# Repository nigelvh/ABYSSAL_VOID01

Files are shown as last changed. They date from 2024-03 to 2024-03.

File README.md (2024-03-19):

# ABYSSAL.NETWORK VOID01
A routing & switching learning platform built around the Raspberry Pi Compute Module 4, and the Microchip KSZ9477 gigabit ethernet switch.

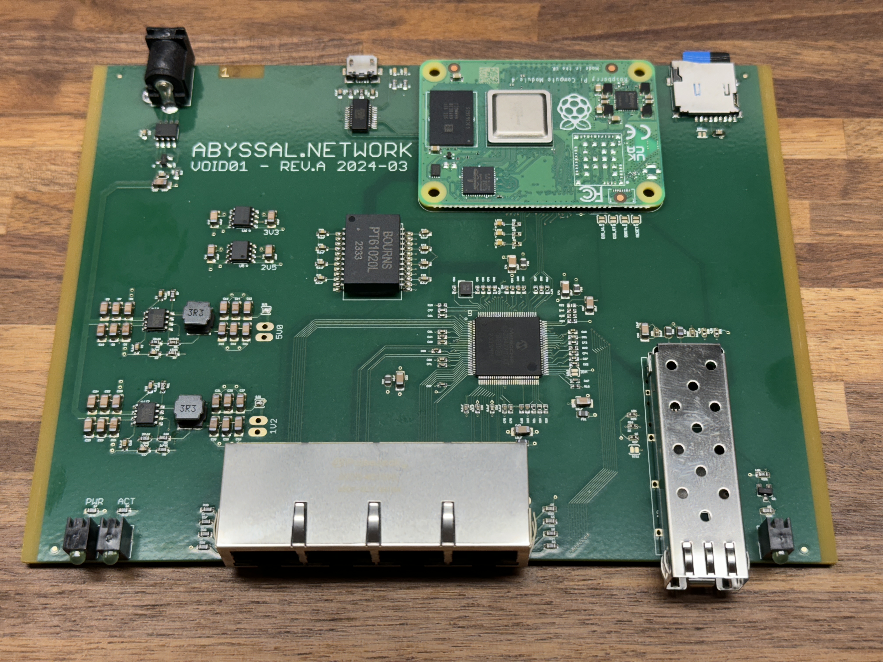
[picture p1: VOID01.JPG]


## Hardware
These are the hardware design files. They're almost certainly terrible. Replicate this device at your own peril.

## Software
The Raspberry Pi Compute Module is installed with standard Raspbian. Configuration of the switching functions of the KSZ9477 are done via scripts communicating via the SPI bus. Configuration of routing functions are as per standard Linux methods.

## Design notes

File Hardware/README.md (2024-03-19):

# ABYSSAL.NETWORK VOID01 Hardware
This is a custom routing and switching learning platform based on the Raspberry Pi Compute Module 4 and the Microchip KSZ9477 gigabit ethernet switch.

The RPi provides for a standard linux platform to enable easy development, with simple scripting to configure the KSZ9477, and linux routing functions. This provides a lower barrier to entry learning platform, as compared to an embedded processor of some sort.

A CM4 Lite module is chosen, utilizing SD card based storage to simplify installation of the RPi OS.

A USB serial interface is provided to allow access to the RPi Serial Console, allowing for non-network based access/recovery.

The KSZ9477 switch is an inexpensive off-the-shelf switching chip, with a relatively rich feature set. Providing 5 PHY interfaces (4 ethernet jacks, and 1 connected to the onboard RPi), 1 RGMII interface (not used), and 1 SGMII interface (SFP Port).

A standard center-positive barrel jack accepts nominal 12V DC power. The input range should be roughly 8-26V. Onboard regulation generates 5V, 3.3V, 2.5V, and 1.2V rails necessary for the RPi and KSZ9477.

## REV A 202403
The first revision of the board. Designed in March 2024.

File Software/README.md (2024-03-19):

# ABYSSAL.NETWORK VOID01 Software
This is a custom routing and switching learning platform based on the Raspberry Pi Compute Module 4 and the Microchip KSZ9477 gigabit ethernet switch.

The software functions remain a work in progress. Primarily based around simple python scripts allowing for control of the KSZ9477 configuration registers over the SPI bus.

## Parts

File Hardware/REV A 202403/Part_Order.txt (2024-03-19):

Index	DigiKey Part #	Manufacturer Part Number	Description	Customer Reference	Quantity	Backorder	Unit Price	Extended Price
1	YAG3023CT-ND	RC0402FR-07191RL	RES 191 OHM 1% 1/16W 0402		10	0	$0.01500	$0.15
2	311-1.00KLRCT-ND	RC0402FR-071KL	RES 1K OHM 1% 1/16W 0402		10	0	$0.01500	$0.15
3	311-4.7KLRCT-ND	RC0402FR-074K7L	RES 4.7K OHM 1% 1/16W 0402		10	0	$0.01500	$0.15
4	YAG2293CT-ND	RC0402FR-076K04L	RES 6.04K OHM 1% 1/16W 0402		10	0	$0.01500	$0.15
5	311-10.0KLRCT-ND	RC0402FR-0710KL	RES 10K OHM 1% 1/16W 0402		10	0	$0.01500	$0.15
6	311-10.0HRCT-ND	RC0603FR-0710RL	RES 10 OHM 1% 1/10W 0603		10	0	$0.02900	$0.29
7	311-22.0HRCT-ND	RC0603FR-0722RL	RES 22 OHM 1% 1/10W 0603		10	0	$0.01900	$0.19
8	311-27.0HRCT-ND	RC0603FR-0727RL	RES 27 OHM 1% 1/10W 0603		10	0	$0.01900	$0.19
9	311-1.00KHRCT-ND	RC0603FR-071KL	RES 1K OHM 1% 1/10W 0603		20	0	$0.01900	$0.38
10	311-3.74KHRCT-ND	RC0603FR-073K74L	RES 3.74K OHM 1% 1/10W 0603		10	0	$0.01900	$0.19
11	311-10.0KHRCT-ND	RC0603FR-0710KL	RES 10K OHM 1% 1/10W 0603		10	0	$0.01900	$0.19
12	311-11.0KHRCT-ND	RC0603FR-0711KL	RES 11K OHM 1% 1/10W 0603		10	0	$0.01900	$0.19
13	311-15.8KHRCT-ND	RC0603FR-0715K8L	RES 15.8K OHM 1% 1/10W 0603		10	0	$0.01900	$0.19
14	311-22.1KHRCT-ND	RC0603FR-0722K1L	RES 22.1K OHM 1% 1/10W 0603		10	0	$0.01900	$0.19
15	311-115KHRCT-ND	RC0603FR-07115KL	RES 115K OHM 1% 1/10W 0603		10	0	$0.01900	$0.19
16	1276-1075-1-ND	CL31A106KAHNNNE	CAP CER 10UF 25V X5R 1206		50	0	$0.07700	$3.85
17	1276-1043-1-ND	CL05A104KA5NNNC	CAP CER 0.1UF 25V X5R 0402		50	0	$0.00540	$0.27
18	1276-1179-1-ND	CL05C150JB5NNNC	CAP CER 15PF 50V C0G/NP0 0402		10	0	$0.02500	$0.25
19	1276-1935-1-ND	CL10B104KB8NNWC	CAP CER 0.1UF 50V X7R 0603		50	0	$0.01020	$0.51
20	311-1809-1-ND	CC0603KRX7R9BB272	CAP CER 2700PF 50V X7R 0603		10	0	$0.05800	$0.58
21	1934-1443-1-ND	2508051217Y3	FERRITE BEAD 120 OHM 0805 1LN		10	0	$0.07100	$0.71
22	2223-MSD-4-ACT-ND	MSD-4-A	MICRO SD CARD CONNECTOR, 9 POSIT		1	0	$0.35000	$0.35
23	CP-002AH-ND	PJ-002AH	CONN PWR JACK 2X5.5MM SOLDER		1	0	$0.69000	$0.69
24	A97430CT-ND	1367073-1	CONN SFP RCPT 20POS SLD R/A SMD		1	0	$1.93000	$1.93
25	A120616-ND	2227302-1	CONN SFP CAGE PRESS-FIT R/A		1	0	$2.23000	$2.23
26	PT61020ELCT-ND	PT61020EL	PULSE XFMR 1CT:1 350UH		1	0	$2.73000	$2.73
27	553-JXD0-4015NL-ND	JXD0-4015NL	CONN JACK 4PORT 1000 BASE-T PCB		1	0	$23.12000	$23.12
28	SRN6045TA-3R3YCT-ND	SRN6045TA-3R3Y	FIXED IND 3.3UH 5A 21 MOHM SMD		2	0	$0.54000	$1.08
29	1516-1224-ND	QBL7YG80D-MP4A	LED CBI 3MM GREEN DIFF RA		3	0	$0.55000	$1.65
30	3147-B1911UD--20D001014U1930CT-ND	B1911UD--20D001014U1930	LED ORANGE DIFFUSED 0603 SMD		10	0	$0.04700	$0.47
31	535-10297-1-ND	ABM8G-25.000MHZ-B4Y-T	CRYSTAL 25.0000MHZ 10PF SMD		1	0	$0.53000	$0.53
32	31-DMP31D1U-7CT-ND	DMP31D1U-7	MOSFET BVDSS: 25V~30V SOT23 T&R		1	0	$0.19000	$0.19
33	DMP4015SSS-13DICT-ND	DMP4015SSS-13	MOSFET P-CH 40V 9.1A 8SO		1	0	$0.81000	$0.81
34	31-AP64501SP-13CT-ND	AP64501SP-13	IC REG BUCK ADJUSTABLE 5A 8SO		2	0	$2.30000	$4.60
35	KSZ9477STXI-CT-ND	KSZ9477STXI-TR	IC ETHERNET SWITCH 7PORT 128TQFP		1	0	$20.91000	$20.91
36	31-AP7361EA-25SP-13CT-ND	AP7361EA-25SP-13	LDO CMOS HICURR SO-8EP T&R 2.5K		1	0	$0.44000	$0.44
37	31-AP7361EA-33SP-13CT-ND	AP7361EA-33SP-13	LDO CMOS HICURR SO-8EP T&R 2.5K		1	0	$0.44000	$0.44
38	MMBZ5242BLT3GOSCT-ND	MMBZ5242BLT3G	DIODE ZENER 12V 225MW SOT23-3		1	0	$0.14000	$0.14
39	2648-SC0683-ND	SC0683	SBC 1.5GHZ 4 CORE 4GB RAM		1	0	$50.00000	$50.00
42	609-4613-1-ND	10118192-0001LF	CONN RCPT USB2.0 MICRO B SMD R/A		1	0	$0.46000	$0.46
43	768-1129-1-ND	FT231XS-R	IC USB SERIAL FULL UART 20SSOP		1	0	$2.34000	$2.34
44	H11615CT-ND	DF40C-100DS-0.4V(51)	CONN RCPT 100POS SMD GOLD		1	0	$1.91000	$1.91

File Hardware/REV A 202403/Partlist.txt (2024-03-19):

Partlist

Exported from CM4_SWITCH.brd at 3/10/24 19:35

EAGLE Version 7.7.0 Copyright (c) 1988-2016 CadSoft

Assembly variant: 

Part     Value                      Package             Library  Position (inch)       Orientation
C85      15pF                       0402-CAP            SparkFun (3.55 2.35)           R90
C86      15pF                       0402-CAP            SparkFun (3.35 2.35)           R270
C37      0.1uF                      0402-CAP            SparkFun (4.35 1.7)            R0
C51      0.1uF                      0402-CAP            SparkFun (4.35 1.9)            R0
C52      0.1uF                      0402-CAP            SparkFun (3.7 2.35)            R90
C54      0.1uF                      0402-CAP            SparkFun (3.8 2.35)            R90
C55      0.1uF                      0402-CAP            SparkFun (3.6 2.35)            R90
C56      0.1uF                      0402-CAP            SparkFun (3.66 1.25)           R270
C57      0.1uF                      0402-CAP            SparkFun (3.25 1.46)           R180
C58      0.1uF                      0402-CAP            SparkFun (3.54 1.25)           R270
C59      0.1uF                      0402-CAP            SparkFun (3.2 1.77)            R180
C60      0.1uF                      0402-CAP            SparkFun (3.25 1.85)           R180
C61      0.1uF                      0402-CAP            SparkFun (3.25 2.1)            R180
C62      0.1uF                      0402-CAP            SparkFun (4.35 1.65)           R0
C64      0.1uF                      0402-CAP            SparkFun (3.25 1.9)            R180
C65      0.1uF                      0402-CAP            SparkFun (3.9 2.35)            R90
C66      0.1uF                      0402-CAP            SparkFun (3.95 2.35)           R90
C67      0.1uF                      0402-CAP            SparkFun (4.35 1.5)            R0
C68      0.1uF                      0402-CAP            SparkFun (4.35 1.95)           R0
C69      0.1uF                      0402-CAP            SparkFun (3.9 1.25)            R270
C70      0.1uF                      0402-CAP            SparkFun (3.81 1.25)           R270
C71      0.1uF                      0402-CAP            SparkFun (3.25 1.64)           R180
C72      0.1uF                      0402-CAP            SparkFun (4.35 1.85)           R0
C74      0.1uF                      0402-CAP            SparkFun (4.35 1.75)           R0
C75      0.1uF                      0402-CAP            SparkFun (3.76 1.25)           R270
C77      0.1uF                      0402-CAP            SparkFun (3.25 2.15)           R180
C78      0.1uF                      0402-CAP            SparkFun (3.45 1.25)           R270
C79      0.1uF                      0402-CAP            SparkFun (3.65 2.35)           R90
C80      0.1uF                      0402-CAP            SparkFun (3.25 1.69)           R180
C81      0.1uF                      0402-CAP            SparkFun (3.25 1.95)           R180
C82      0.1uF                      0402-CAP            SparkFun (4.1 2.35)            R90
C83      0.1uF                      0402-CAP            SparkFun (3.95 1.25)           R270
C84      0.1uF                      0402-CAP            SparkFun (3.85 2.35)           R90
C88      0.1uF                      0402-CAP            SparkFun (5.05 1.95)           R90
C90      0.1uF                      0402-CAP            SparkFun (5.35 1.95)           R90

C2       2.7nF                      0603-CAP            SparkFun (0.85 1.75)           R180
C17      2.7nF                      0603-CAP            SparkFun (0.85 0.9)            R180
C3       0.1uF                      0603-CAP            SparkFun (0.7 1.8)             R270
C4       0.1uF                      0603-CAP            SparkFun (0.85 2.3)            R90
C18      0.1uF                      0603-CAP            SparkFun (0.7 0.95)            R270
C19      0.1uF                      0603-CAP            SparkFun (0.85 1.45)           R90
C32      0.1uF                      0603-CAP            SparkFun (0.55 3.95)           R270
C34      0.1uF                      0603-CAP            SparkFun (0.75 3.5)            R0
C35      0.1uF                      0603-CAP            SparkFun (2.3 4.4)             R270
C36      0.1uF                      0603-CAP            SparkFun (2.6 4.4)             R90
C38      0.1uF                      0603-CAP            SparkFun (2.2 2.9)             R0
C39      0.1uF                      0603-CAP            SparkFun (2.2 2.75)            R0
C40      0.1uF                      0603-CAP            SparkFun (2.2 2.6)             R0
C41      0.1uF                      0603-CAP            SparkFun (2.2 2.45)            R0
C42      0.1uF                      0603-CAP            SparkFun (3.1 2.9)             R0
C43      0.1uF                      0603-CAP            SparkFun (3.1 2.75)            R0
C44      0.1uF                      0603-CAP            SparkFun (3.1 2.6)             R0
C45      0.1uF                      0603-CAP            SparkFun (3.1 2.45)            R0
C1       0.1uF                      0603-CAP            SparkFun (5.75 3.95)           R180

C5       10uF                       1206                SparkFun (0.6 2.15)            R90
C6       10uF                       1206                SparkFun (0.6 1.95)            R270
C7       10uF                       1206                SparkFun (0.5 2.15)            R90
C8       10uF                       1206                SparkFun (0.5 1.95)            R270
C9       10uF                       1206                SparkFun (0.4 2.15)            R90
C10      10uF                       1206                SparkFun (0.4 1.95)            R270
C11      10uF                       1206                SparkFun (1.6 1.95)            R270
C12      10uF                       1206                SparkFun (1.6 2.15)            R90
C13      10uF                       1206                SparkFun (1.5 1.95)            R270
C14      10uF                       1206                SparkFun (1.5 2.15)            R90
C15      10uF                       1206                SparkFun (1.4 1.95)            R270
C16      10uF                       1206                SparkFun (1.4 2.15)            R90
C20      10uF                       1206                SparkFun (0.6 1.3)             R90
C21      10uF                       1206                SparkFun (0.6 1.1)             R270
C22      10uF                       1206                SparkFun (0.5 1.3)             R90
C23      10uF                       1206                SparkFun (0.5 1.1)             R270
C24      10uF                       1206                SparkFun (0.4 1.3)             R90
C25      10uF                       1206                SparkFun (0.4 1.1)             R270
C26      10uF                       1206                SparkFun (1.6 1.1)             R270
C27      10uF                       1206                SparkFun (1.6 1.3)             R90
C28      10uF                       1206                SparkFun (1.5 1.1)             R270
C29      10uF                       1206                SparkFun (1.5 1.3)             R90
C30      10uF                       1206                SparkFun (1.4 1.1)             R270
C31      10uF                       1206                SparkFun (1.4 1.3)             R90
C33      10uF                       1206                SparkFun (0.75 3.4)            R0
C46      10uF                       1206                SparkFun (1.25 2.7)            R90
C47      10uF                       1206                SparkFun (1.25 3.05)           R90
C48      10uF                       1206                SparkFun (1.75 2.7)            R90
C49      10uF                       1206                SparkFun (1.75 3.05)           R90
C50      10uF                       1206                SparkFun (4.4 1.3)             R0
C53      10uF                       1206                SparkFun (2.9 1.5)             R270
C63      10uF                       1206                SparkFun (3.9 1.05)            R0
C73      10uF                       1206                SparkFun (4.3 2.35)            R90
C76      10uF                       1206                SparkFun (3.85 2.6)            R90
C87      10uF                       1206                SparkFun (4.5 2.2)             R90
C89      10uF                       1206                SparkFun (4.95 1.95)           R90

FB1                                 0805                SparkFun (4.4 1.2)             R180
FB2                                 0805                SparkFun (2.8 1.5)             R90
FB3                                 0805                SparkFun (3.9 0.95)            R180
FB4                                 0805                SparkFun (4.4 2.35)            R270
FB5                                 0805                SparkFun (3.95 2.6)            R270
FB6                                 0805                SparkFun (5.15 1.95)           R270
FB7                                 0805                SparkFun (5.25 1.95)           R270

FID1     FIDUCIAL                   FIDUCIAL            Nigel    (0.25 0.1)            R0
FID2     FIDUCIAL                   FIDUCIAL            Nigel    (6.05 0.1)            R0
FID3     FIDUCIAL                   FIDUCIAL            Nigel    (6.05 4.6)            R0
FID4     FIDUCIAL                   FIDUCIAL            Nigel    (0.25 4.6)            R0

J1       MICROSD                    MSD-4-A             Nigel    (5.65 4.55)           R180
J2       POWER_JACKPTH              POWER_JACK_PTH      SparkFun (0.75 4.8)            R180
J3       SFP+                       SFP_SOCKET_CAGE     Nigel    (4.95 1.4)            R90
J4       JXD0-4015NL                JXD0-4015NL         Nigel    (2.75 0.35)           R0

JP1                                 1X02_LONGPADS       SparkFun (1.75 2)              R270
JP2                                 1X02_LONGPADS       SparkFun (1.75 1.15)           R270

L1       3.3uH                      SRN6045TA           Nigel    (1.2 2.05)            R0
L2       3.3uH                      SRN6045TA           Nigel    (1.2 1.2)             R0

LED1     G                          LED-0603            SparkFun (3.75 2.8)            R270
LED2     Y                          LED-0603            SparkFun (3.75 2.9)            R270
LED3     G                          LED-0603            SparkFun (3.75 3)              R270
LED5     G                          LED-0603            SparkFun (2.8 4.65)            R0
LED7     G                          LED-0603            SparkFun (2.9 4.65)            R0
LED4     LED                        LED_QBL7XX80D-MP4A  Nigel    (0.5 0.2)             R0
LED6     LED                        LED_QBL7XX80D-MP4A  Nigel    (5.8 0.2)             R0
LED8     LED                        LED_QBL7XX80D-MP4A  Nigel    (0.75 0.2)            R0

Q1       MOSFET_P_CHANNELDMP4015SSS SO08                Nigel    (0.75 3.95)           R0
Q3       MOSFET_P_CHANNELAO3423     SOT-23              Nigel    (5.8 0.55)            R180

Q2                                  CRYSTAL_3.2X2.5     Nigel    (3.45 2.35)           R270

R22      191R                       0402-RES            SparkFun (4.35 1.8)            R0
R1       1K                         0402-RES            SparkFun (3.9 2.8)             R0
R2       1K                         0402-RES            SparkFun (3.9 2.9)             R0
R3       1K                         0402-RES            SparkFun (3.9 3)               R0
R26      1K                         0402-RES            SparkFun (4.8 1.1)             R0
R27      1K                         0402-RES            SparkFun (4.8 1)               R180
R16      4.7K                       0402-RES            SparkFun (4.15 2.35)           R90
R17      4.7K                       0402-RES            SparkFun (4.05 2.35)           R90
R30      4.7K                       0402-RES            SparkFun (5.45 1.95)           R270
R31      4.7K                       0402-RES            SparkFun (5.55 1.95)           R270
R15      6.04K                      0402-RES            SparkFun (3.25 2.2)            R180
R18      10K                        0402-RES            SparkFun (4.35 1.45)           R0
R19      10K                        0402-RES            SparkFun (4.1 1.25)            R270
R20      10K                        0402-RES            SparkFun (4.05 1.25)           R270
R21      10K                        0402-RES            SparkFun (4 1.25)              R270
R24      10K                        0402-RES            SparkFun (4.35 2.05)           R0
R25      10K                        0402-RES            SparkFun (4.35 2.1)            R0
R29      10K                        0402-RES            SparkFun (4.8 1.2)             R180
R44      10K                        0402-RES            SparkFun (4.35 2.15)           R0
R23      DNP                        0402-RES            SparkFun (4.35 2.2)            R0

R7       10R                        0603-RES            SparkFun (0.95 2.3)            R270
R11      22R                        0603-RES            SparkFun (0.95 1.45)           R270
R13      27                         0603-RES            SparkFun (2.5 4.4)             R270
R14      27                         0603-RES            SparkFun (2.4 4.4)             R270
R32      1K                         0603-RES            SparkFun (4.1 0.4)             R180
R33      1K                         0603-RES            SparkFun (4.1 0.3)             R180
R34      1K                         0603-RES            SparkFun (4.1 0.2)             R180
R35      1K                         0603-RES            SparkFun (4.1 0.1)             R180
R36      1K                         0603-RES            SparkFun (1.4 0.1)             R0
R37      1K                         0603-RES            SparkFun (1.4 0.3)             R0
R38      1K                         0603-RES            SparkFun (1.4 0.2)             R0
R39      1K                         0603-RES            SparkFun (1.4 0.4)             R0
R40      1K                         0603-RES            SparkFun (0.5 0.4)             R180
R41      1K                         0603-RES            SparkFun (2.8 4.5)             R90
R42      1K                         0603-RES            SparkFun (2.9 4.5)             R90
R43      1K                         0603-RES            SparkFun (0.75 0.4)            R180
R45      1K                         0603-RES            SparkFun (5.8 0.4)             R180
R8       3.74K                      0603-RES            SparkFun (1 0.9)               R180
R12      10K                        0603-RES            SparkFun (0.875 3.52)          R270
R28      10K                        0603-RES            SparkFun (5.8 0.7)             R180
R9       11K                        0603-RES            SparkFun (1 1)                 R180
R4       15.8K                      0603-RES            SparkFun (1 1.75)              R180
R6       22.1K                      0603-RES            SparkFun (0.85 1.85)           R180
R10      22.1K                      0603-RES            SparkFun (0.85 1)              R180
R5       115.8K                     0603-RES            SparkFun (1 1.85)              R180

SJ1                                 SJ_2S-TRACE         SparkFun (5.6 3.95)            R0
SJ2      NC                         SJ_2S-TRACE         SparkFun (4.5 3.45)            R270
SJ3      NO                         SJ_2S-NO            SparkFun (4.5 3.55)            R90
SJ4      NO                         SJ_2S-NO            SparkFun (4.65 3.05)           R90
SJ5      NO                         SJ_2S-NO            SparkFun (4.75 3.05)           R90
SJ6      NO                         SJ_2S-NO            SparkFun (4.85 3.05)           R90
SJ7      NO                         SJ_2S-NO            SparkFun (4.95 3.05)           R90
SJ8      NO                         SJ_2S-NO            SparkFun (1.75 1.3)            R0
SJ9      NO                         SJ_2S-NO            SparkFun (1.75 2.15)           R0
SJ10     NO                         SJ_2S-NO            SparkFun (4.35 1.58)           R90
SJ11     NO                         SJ_2S-NO            SparkFun (4.8 0.9)             R180

T1       HX6098NL                   HX6098NL            Nigel    (2.65 2.65)           R270
U$1      RPI-CM4                    RPI-CM4             Nigel    (5.2 4.7)             R180
         CM4 Hirose Connector		DF40C-100DS-0.4V(51)
U$2      USB-MICROB                 USB-MICROB-10118192 Nigel    (2.5 4.65)            R180
U1       AP64501                    SO-8EP              Nigel    (0.85 2.05)           R90
U2       AP64501                    SO-8EP              Nigel    (0.85 1.2)            R90
U3       KSZ9477S                   TQFP-128-EP         Nigel    (3.8 1.8)             R270
U4       FT231XS                    SSOP-20             Nigel    (2.5 4.1)             R90
U5       AP7361EA-25SP-13           SO-8EP              Nigel    (1.5 2.7)             R270
U6       AP7361EA-33SP-13           SO-8EP              Nigel    (1.5 3.05)            R270
Z1       12V                        SOT-23              Nigel    (0.75 3.65)           R90

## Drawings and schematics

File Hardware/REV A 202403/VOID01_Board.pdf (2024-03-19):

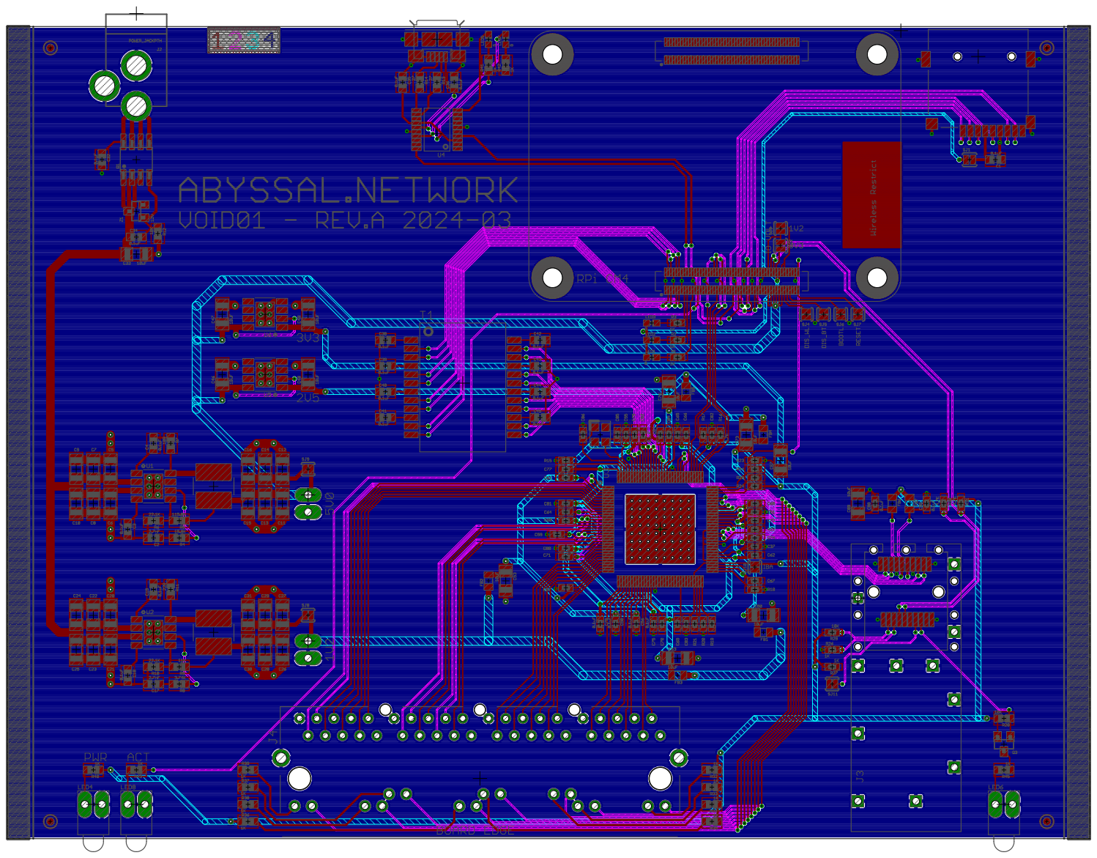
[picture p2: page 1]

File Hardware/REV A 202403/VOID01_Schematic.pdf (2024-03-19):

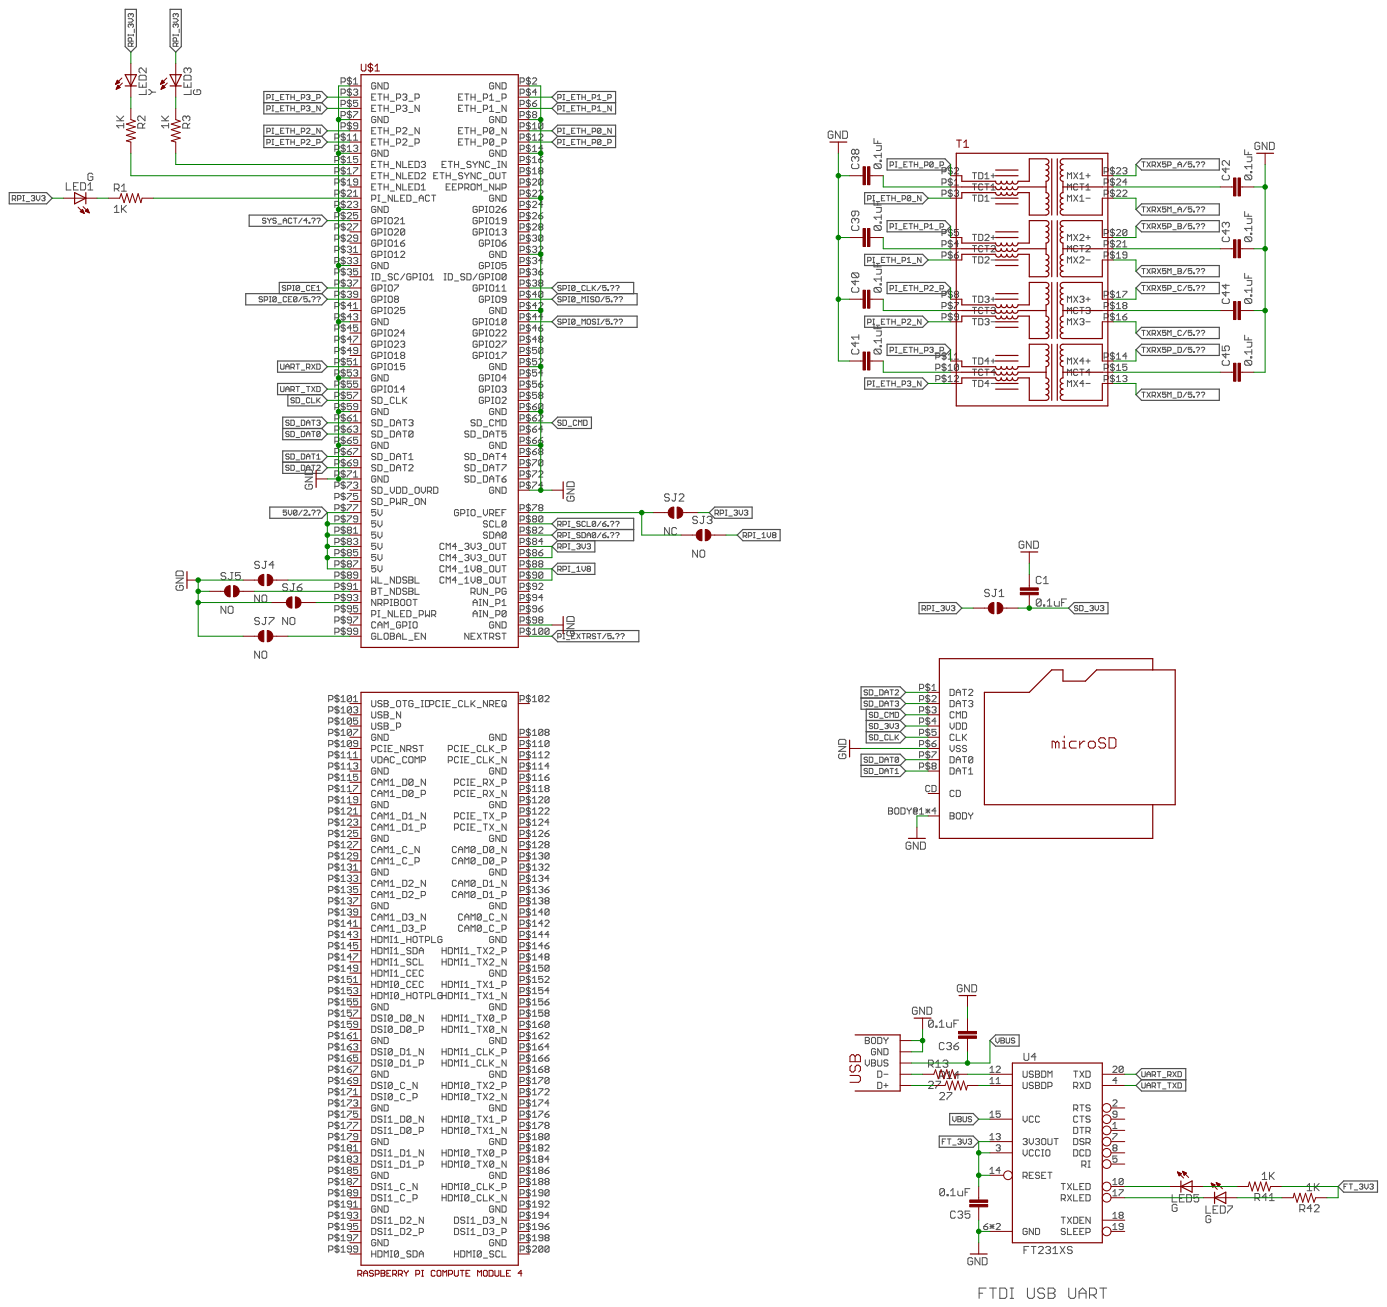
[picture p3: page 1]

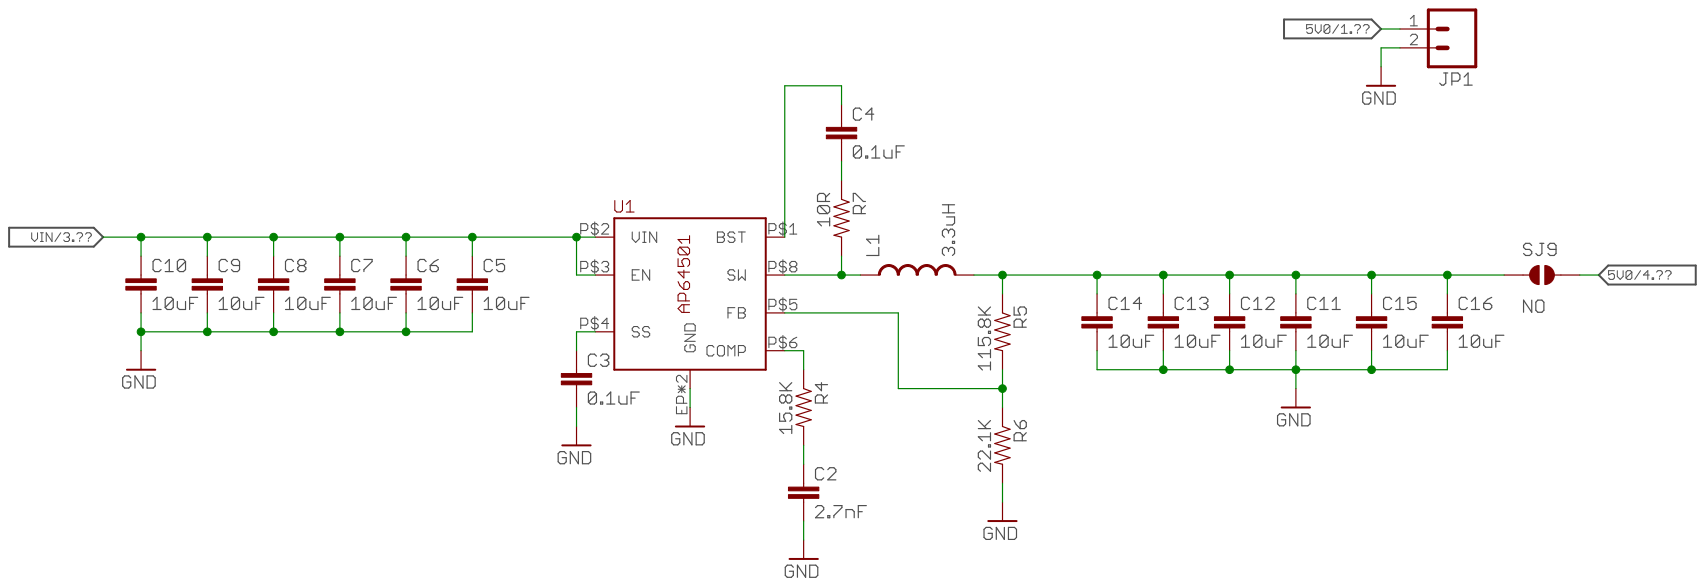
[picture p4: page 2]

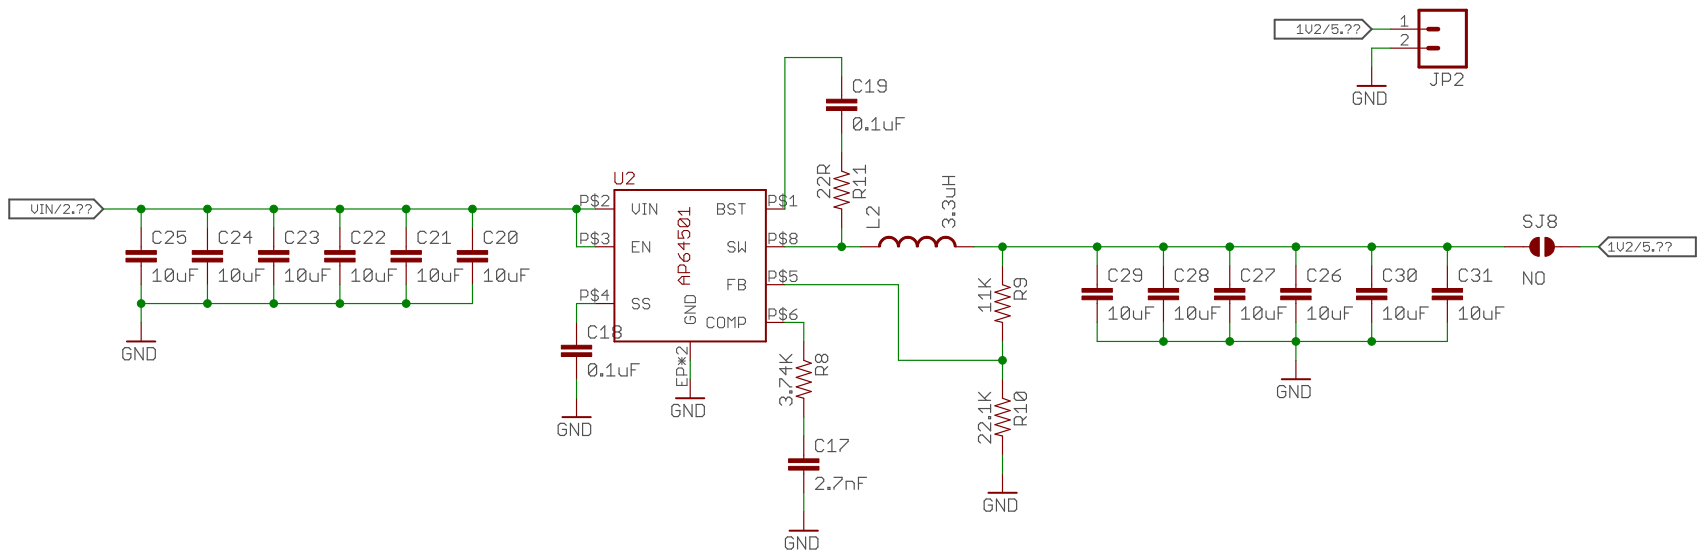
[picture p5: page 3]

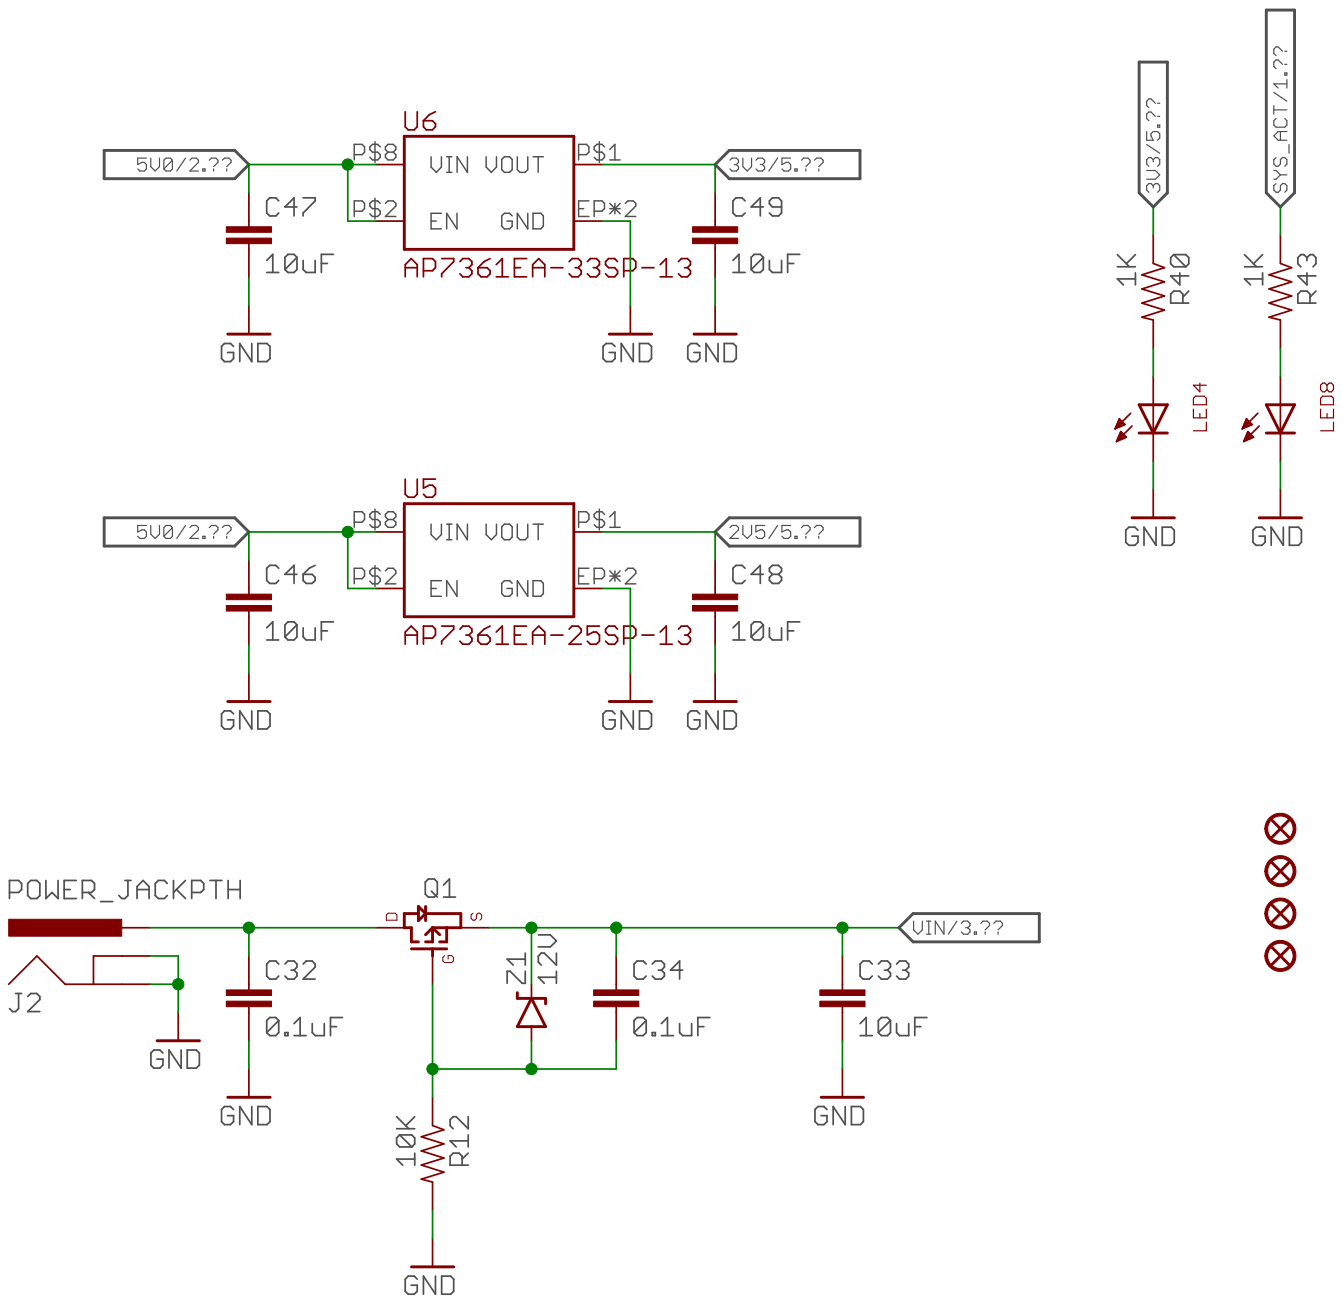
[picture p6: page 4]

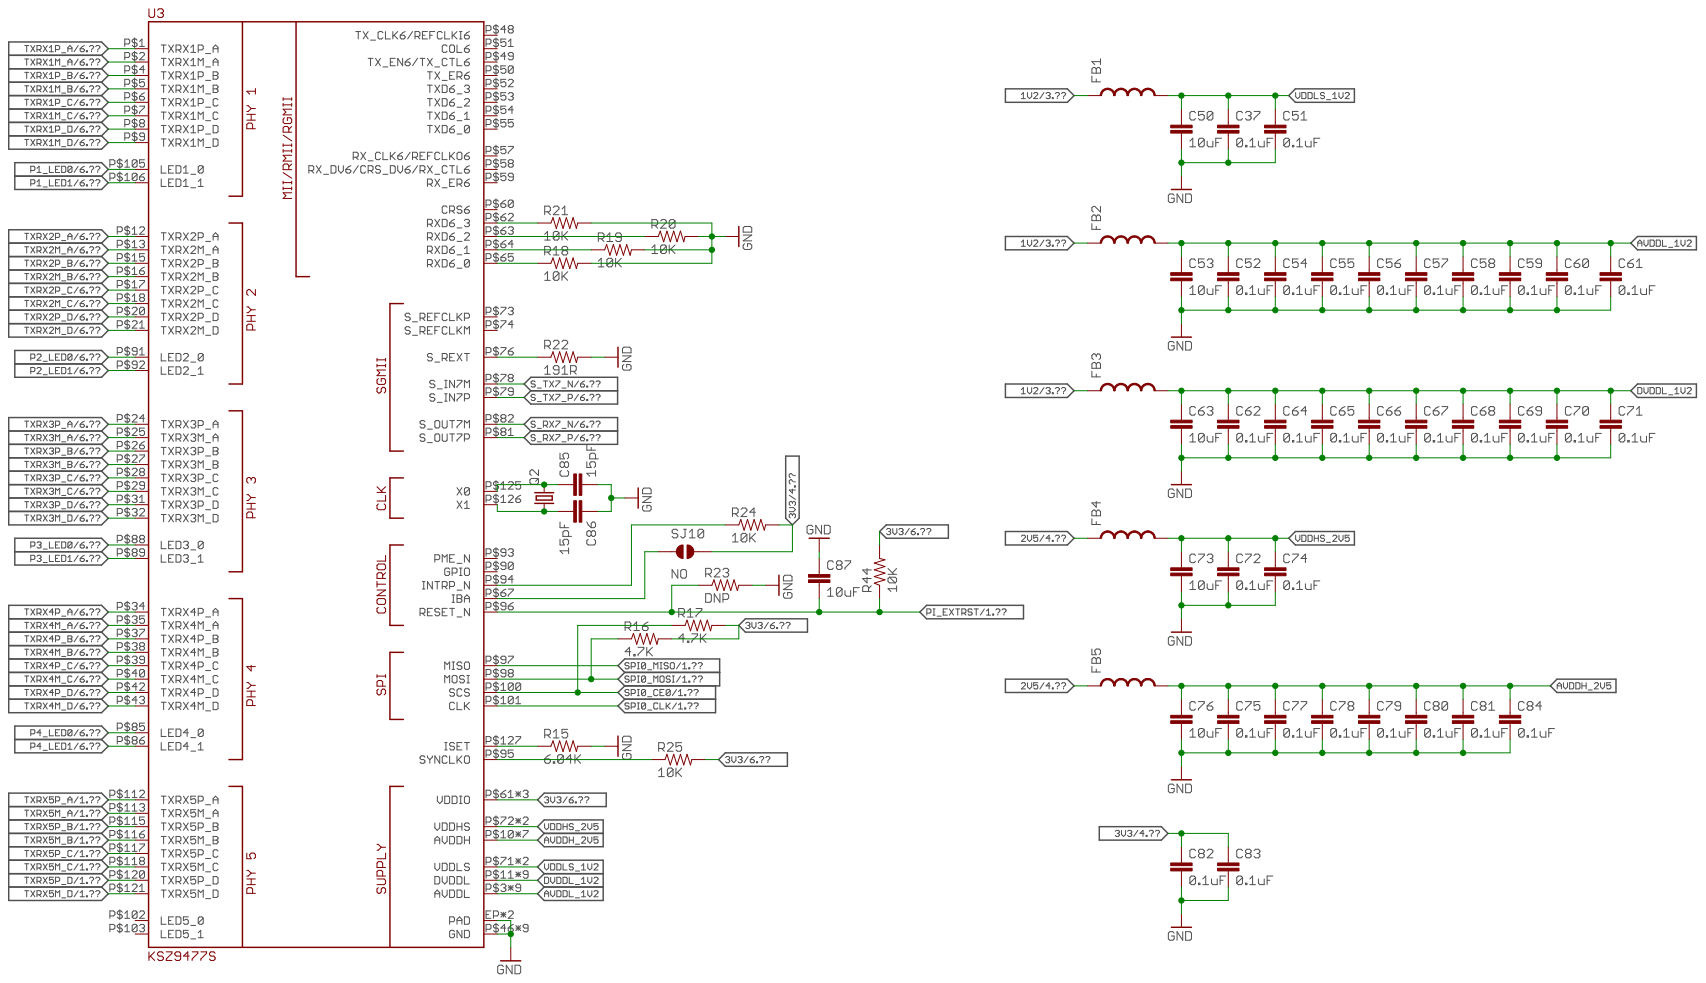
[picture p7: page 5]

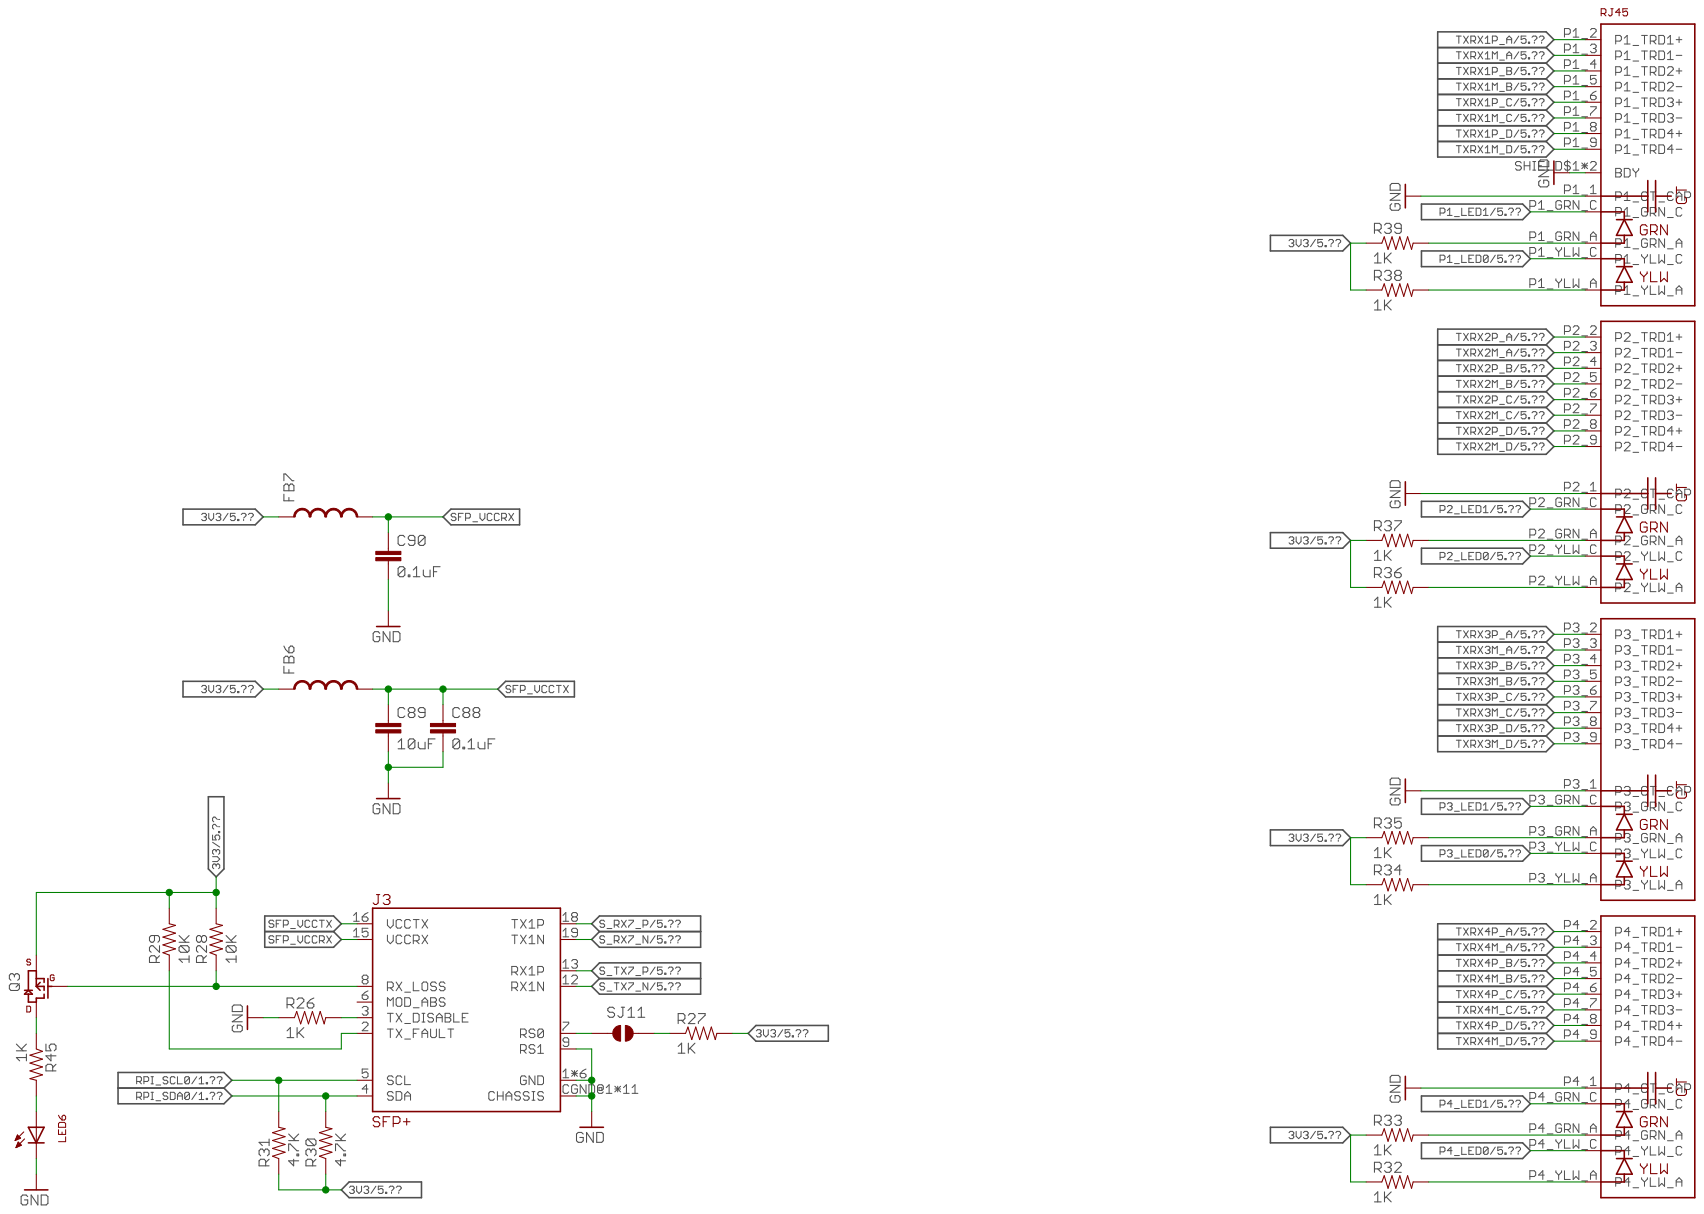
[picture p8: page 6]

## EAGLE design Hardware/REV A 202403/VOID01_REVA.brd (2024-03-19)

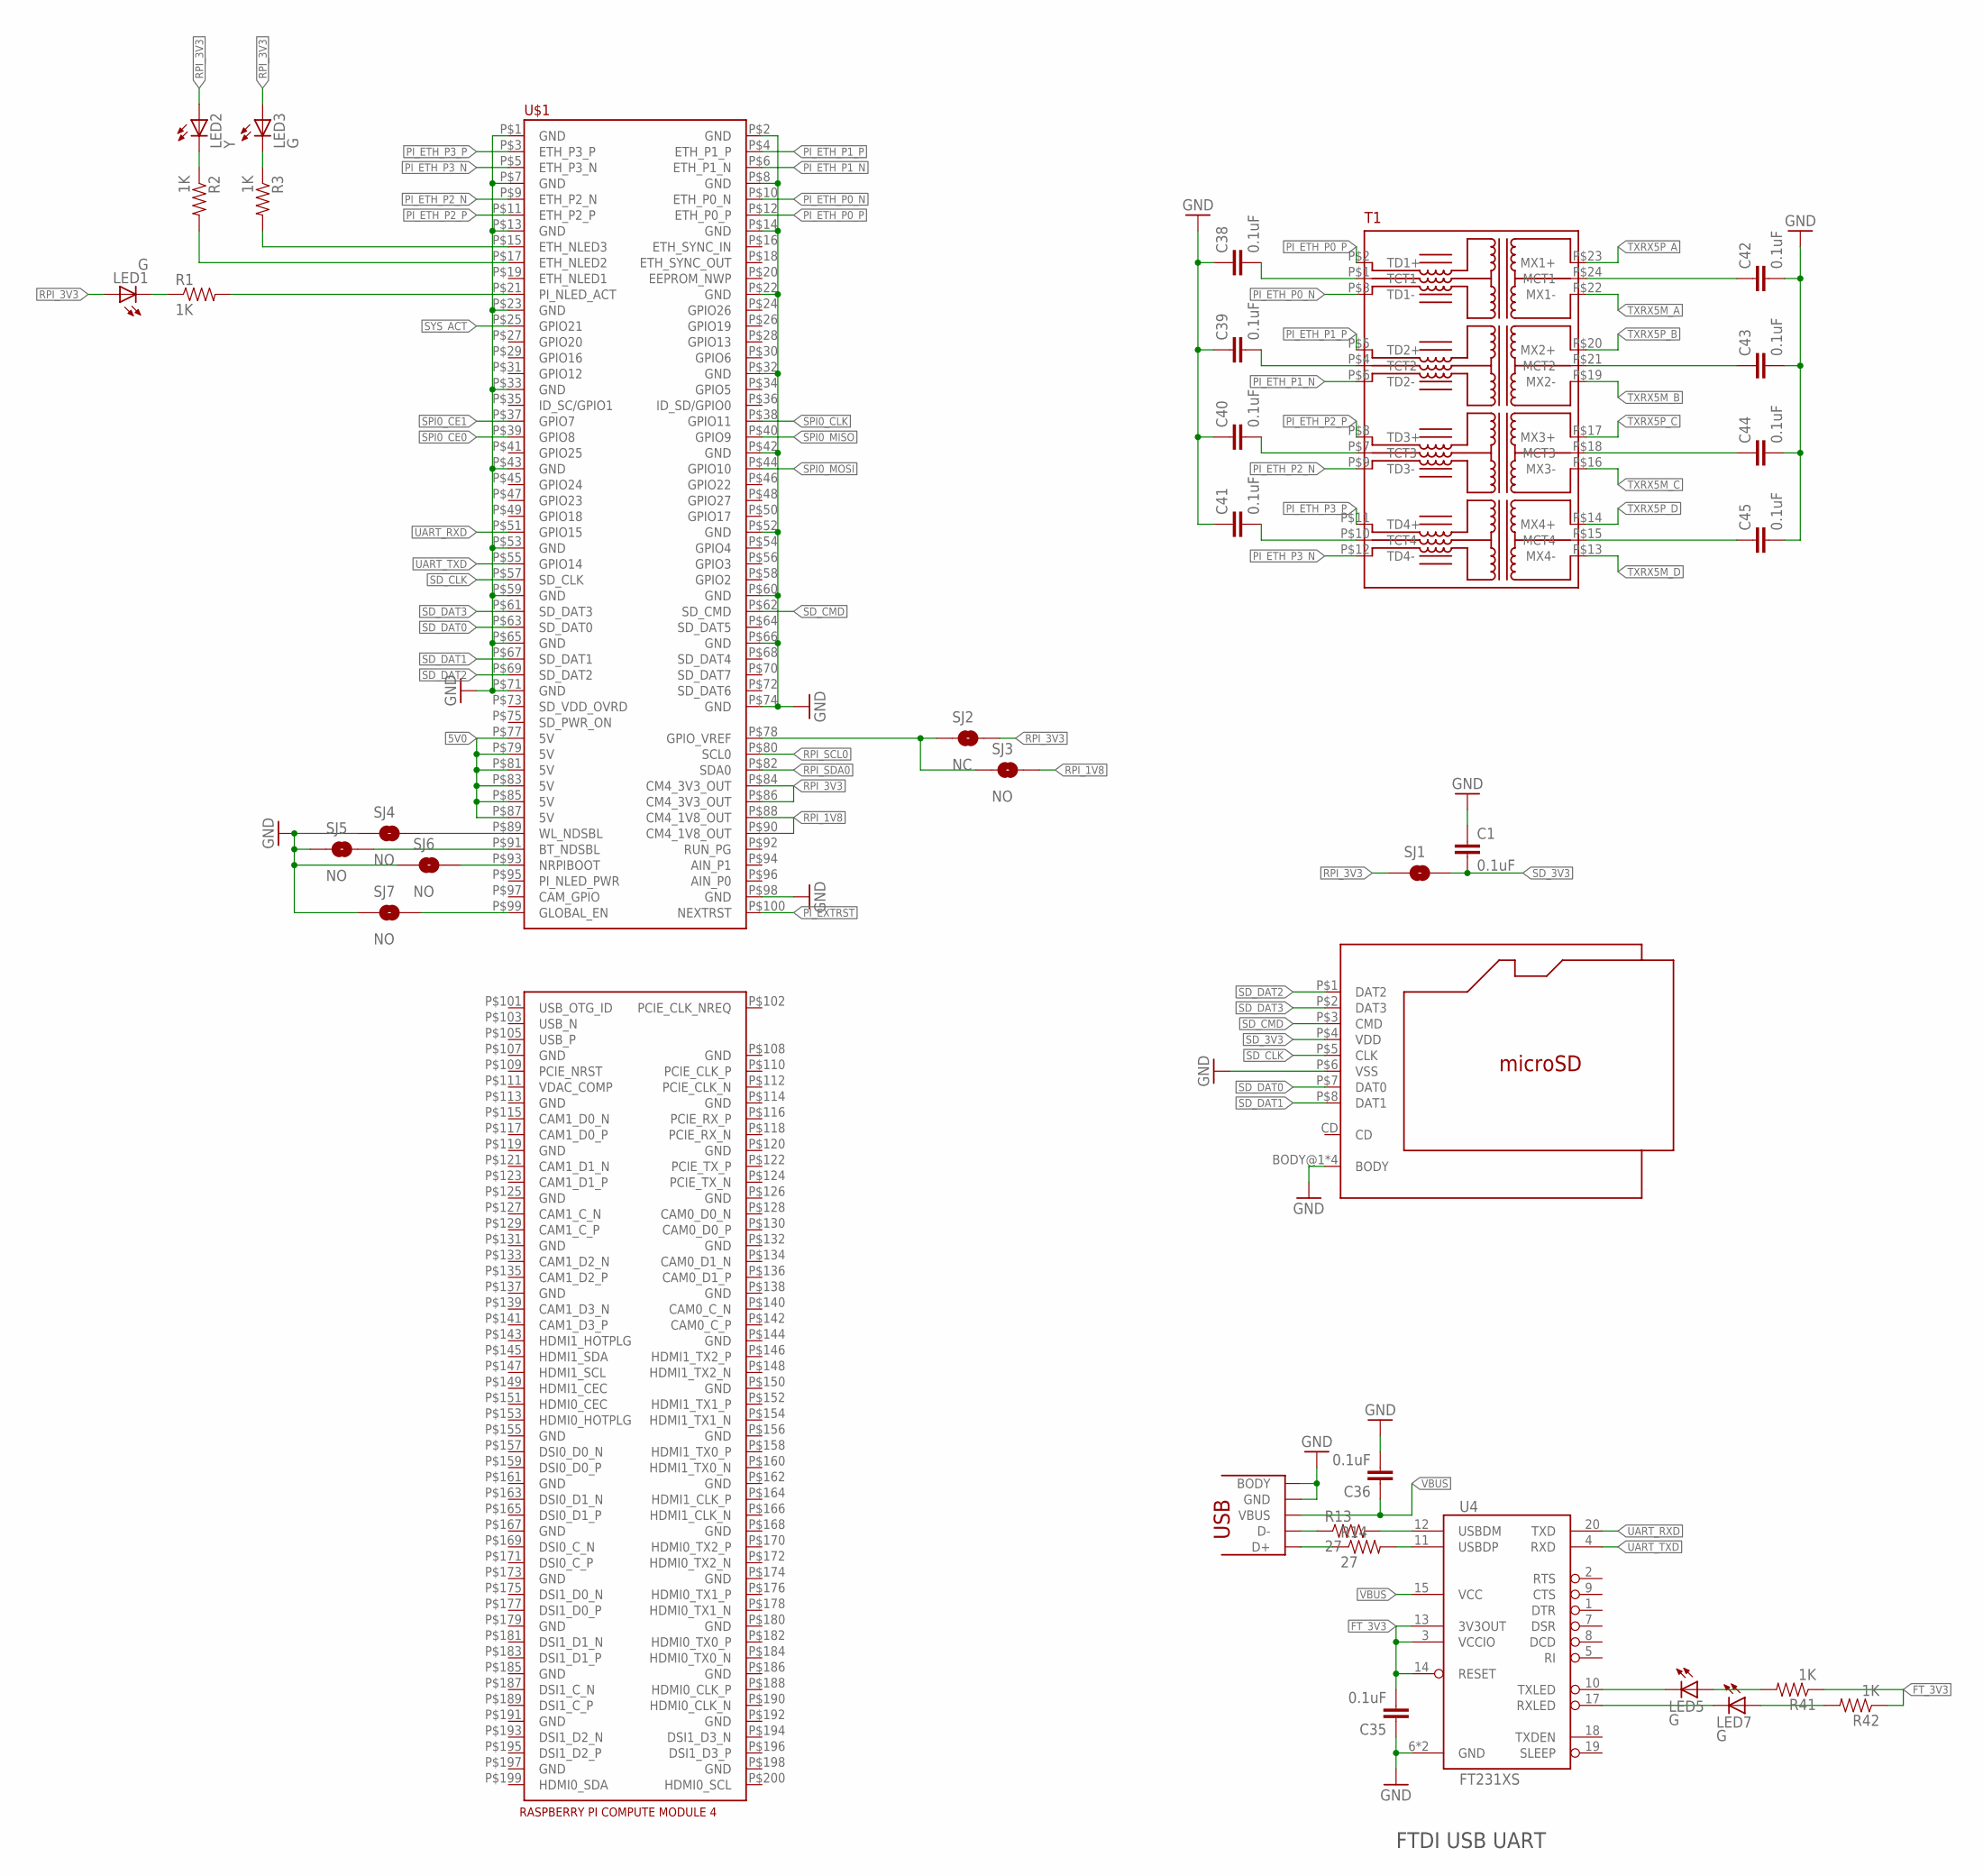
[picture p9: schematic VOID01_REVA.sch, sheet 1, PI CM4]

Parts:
C1, C35, C36, C38, C39, C40, C41, C42, C43, C44, C45: 0.1uF; 0603-CAP
J1: MICROSD; MSD-4-A
LED1, LED3, LED5, LED7: G; LED-0603
LED2: Y; LED-0603
R1, R2, R3: 1K; 0402-RES
R13, R14: 27; 0603-RES
R41, R42: 1K; 0603-RES
SJ1: SOLDERJUMPERTRACE; SJ_2S-TRACE
SJ2: NC; SJ_2S-TRACE
SJ3, SJ4, SJ5, SJ6, SJ7: NO; SJ_2S-NO
T1: HX6098NL
U4: FT231XS; SSOP-20
U$1: RPI-CM4
U$2: USB-MICROB; USB-MICROB-10118192

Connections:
5V0: U$1.P$77 (5V), U$1.P$79 (5V), U$1.P$81 (5V), U$1.P$83 (5V), U$1.P$85 (5V), U$1.P$87 (5V); also elsewhere on the board
FT_3V3: C35.2, R41.1, R42.1, U4.3 (VCCIO), U4.13 (3V3OUT), U4.14 (RESET)
GND: C1.1, C35.1, C36.2, C38.1, C39.1, C40.1, C41.1, C42.2, C43.2, C44.2, C45.2, J1.BODY@1 (BODY), J1.BODY@2 (BODY), J1.BODY@3 (BODY), J1.BODY@4 (BODY), J1.P$6 (VSS), SJ4.1, SJ5.1, SJ6.1, SJ7.1, U4.6 (GND), U4.16 (GND), U$1.P$1 (GND), U$1.P$2 (GND), U$1.P$7 (GND), U$1.P$8 (GND), U$1.P$13 (GND), U$1.P$14 (GND), U$1.P$22 (GND), U$1.P$23 (GND), U$1.P$32 (GND), U$1.P$33 (GND), U$1.P$42 (GND), U$1.P$43 (GND), U$1.P$52 (GND), U$1.P$53 (GND), U$1.P$59 (GND), U$1.P$60 (GND), U$1.P$65 (GND), U$1.P$66 (GND), U$1.P$71 (GND), U$1.P$74 (GND), U$1.P$98 (GND), U$2.5 (GND), U$2.BODY@1 (BODY), U$2.BODY@2 (BODY), U$2.BODY@3 (BODY), U$2.BODY@4 (BODY), U$2.BODY@5 (BODY), U$2.BODY@6 (BODY); also elsewhere on the board
unnamed: SJ2.1, SJ3.1, U$1.P$78 (GPIO_VREF)
unnamed: SJ4.2, U$1.P$89 (WL_NDSBL)
unnamed: SJ5.2, U$1.P$91 (BT_NDSBL)
unnamed: LED2.C, R2.1
unnamed: SJ6.2, U$1.P$93 (NRPIBOOT)
unnamed: R1.2, U$1.P$21 (PI_NLED_ACT)
unnamed: LED1.C, R1.1
unnamed: LED3.C, R3.1
unnamed: R2.2, U$1.P$17 (ETH_NLED2)
unnamed: R3.2, U$1.P$15 (ETH_NLED3)
unnamed: SJ7.2, U$1.P$99 (GLOBAL_EN)
unnamed: R13.1, U$2.2 (D-)
unnamed: R14.1, U$2.3 (D+)
unnamed: R14.2, U4.11 (USBDP)
unnamed: R13.2, U4.12 (USBDM)
unnamed: C38.2, T1.P$1 (TCT1)
unnamed: C39.2, T1.P$4 (TCT2)
unnamed: C40.2, T1.P$7 (TCT3)
unnamed: C41.2, T1.P$10 (TCT4)
unnamed: C45.1, T1.P$15 (MCT4)
unnamed: C44.1, T1.P$18 (MCT3)
unnamed: C43.1, T1.P$21 (MCT2)
unnamed: C42.1, T1.P$24 (MCT1)
unnamed: LED5.C, U4.10 (TXLED)
unnamed: LED5.A, R41.2
unnamed: LED7.C, U4.17 (RXLED)
unnamed: LED7.A, R42.2
PI_ETH_P0_N: T1.P$3 (TD1-), U$1.P$10 (ETH_P0_N)
PI_ETH_P0_P: T1.P$2 (TD1+), U$1.P$12 (ETH_P0_P)
PI_ETH_P1_N: T1.P$6 (TD2-), U$1.P$6 (ETH_P1_N)
PI_ETH_P1_P: T1.P$5 (TD2+), U$1.P$4 (ETH_P1_P)
PI_ETH_P2_N: T1.P$9 (TD3-), U$1.P$9 (ETH_P2_N)
PI_ETH_P2_P: T1.P$8 (TD3+), U$1.P$11 (ETH_P2_P)
PI_ETH_P3_N: T1.P$12 (TD4-), U$1.P$5 (ETH_P3_N)
PI_ETH_P3_P: T1.P$11 (TD4+), U$1.P$3 (ETH_P3_P)
PI_EXTRST: U$1.P$100 (NEXTRST); also elsewhere on the board
RPI_1V8: SJ3.2, U$1.P$88 (CM4_1V8_OUT), U$1.P$90 (CM4_1V8_OUT)
RPI_3V3: LED1.A, LED2.A, LED3.A, SJ1.1, SJ2.2, U$1.P$84 (CM4_3V3_OUT), U$1.P$86 (CM4_3V3_OUT)
RPI_SCL0: U$1.P$80 (SCL0); also elsewhere on the board
RPI_SDA0: U$1.P$82 (SDA0); also elsewhere on the board
SD_3V3: C1.2, J1.P$4 (VDD), SJ1.2
SD_CLK: J1.P$5 (CLK), U$1.P$57 (SD_CLK)
SD_CMD: J1.P$3 (CMD), U$1.P$62 (SD_CMD)
SD_DAT0: J1.P$7 (DAT0), U$1.P$63 (SD_DAT0)
SD_DAT1: J1.P$8 (DAT1), U$1.P$67 (SD_DAT1)
SD_DAT2: J1.P$1 (DAT2), U$1.P$69 (SD_DAT2)
SD_DAT3: J1.P$2 (DAT3), U$1.P$61 (SD_DAT3)
SPI0_CE0: U$1.P$39 (GPIO8); also elsewhere on the board
SPI0_CE1: U$1.P$37 (GPIO7)
SPI0_CLK: U$1.P$38 (GPIO11); also elsewhere on the board
SPI0_MISO: U$1.P$40 (GPIO9); also elsewhere on the board
SPI0_MOSI: U$1.P$44 (GPIO10); also elsewhere on the board
SYS_ACT: U$1.P$25 (GPIO21); also elsewhere on the board
TXRX5M_A: T1.P$22 (MX1-); also elsewhere on the board
TXRX5M_B: T1.P$19 (MX2-); also elsewhere on the board
TXRX5M_C: T1.P$16 (MX3-); also elsewhere on the board
TXRX5M_D: T1.P$13 (MX4-); also elsewhere on the board
TXRX5P_A: T1.P$23 (MX1+); also elsewhere on the board
TXRX5P_B: T1.P$20 (MX2+); also elsewhere on the board
TXRX5P_C: T1.P$17 (MX3+); also elsewhere on the board
TXRX5P_D: T1.P$14 (MX4+); also elsewhere on the board
UART_RXD: U4.20 (TXD), U$1.P$51 (GPIO15)
UART_TXD: U4.4 (RXD), U$1.P$55 (GPIO14)
VBUS: C36.1, U4.15 (VCC), U$2.1 (VBUS)

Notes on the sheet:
FTDI USB UART

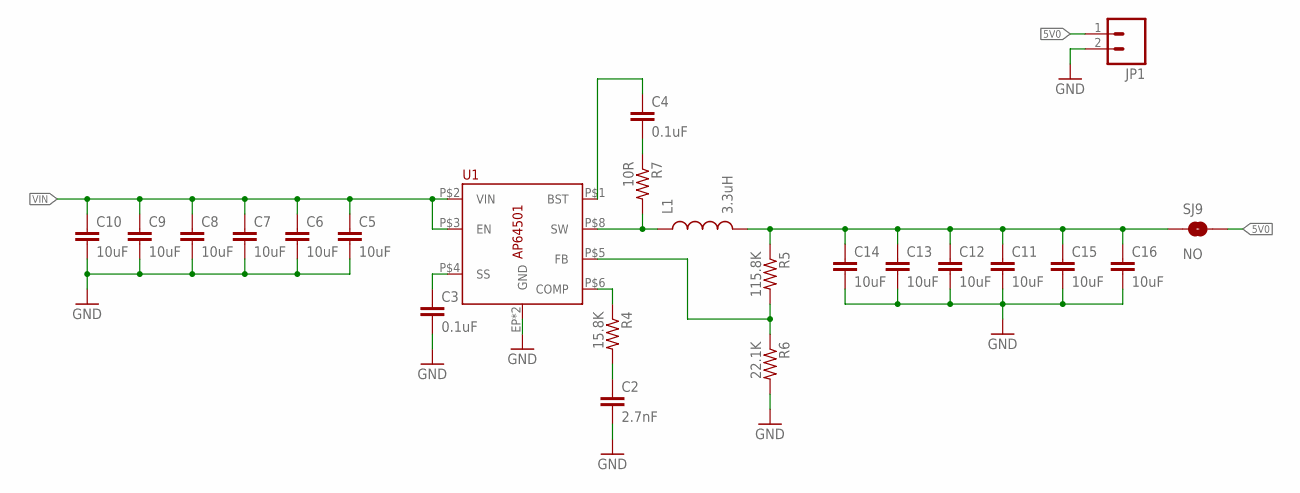
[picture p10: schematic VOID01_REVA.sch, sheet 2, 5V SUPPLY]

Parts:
C2: 2.7nF; 0603-CAP
C3, C4: 0.1uF; 0603-CAP
C5, C6, C7, C8, C9, C10, C11, C12, C13, C14, C15, C16: 10uF; 1206
JP1: M02PTH3; 1X02_LONGPADS
L1: 3.3uH; SRN6045TA
R4: 15.8K; 0603-RES
R5: 115.8K; 0603-RES
R6: 22.1K; 0603-RES
R7: 10R; 0603-RES
SJ9: NO; SJ_2S-NO
U1: AP64501; SO-8EP

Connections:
5V0: JP1.1, SJ9.2; also elsewhere on the board
GND: C2.2, C3.2, C5.2, C6.2, C7.2, C8.2, C9.2, C10.2, C11.2, C12.2, C13.2, C14.2, C15.2, C16.2, JP1.2, R6.2, U1.EP (GND), U1.P$7 (GND); also elsewhere on the board
unnamed: C3.1, U1.P$4 (SS)
unnamed: R4.1, U1.P$6 (COMP)
unnamed: C2.1, R4.2
unnamed: R5.2, R6.1, U1.P$5 (FB)
unnamed: L1.P$1 (1), R7.2, U1.P$8 (SW)
unnamed: C4.2, R7.1
unnamed: C4.1, U1.P$1 (BST)
unnamed: C11.1, C12.1, C13.1, C14.1, C15.1, C16.1, L1.P$2 (2), R5.1, SJ9.1
VIN: C5.1, C6.1, C7.1, C8.1, C9.1, C10.1, U1.P$2 (VIN), U1.P$3 (EN); also elsewhere on the board

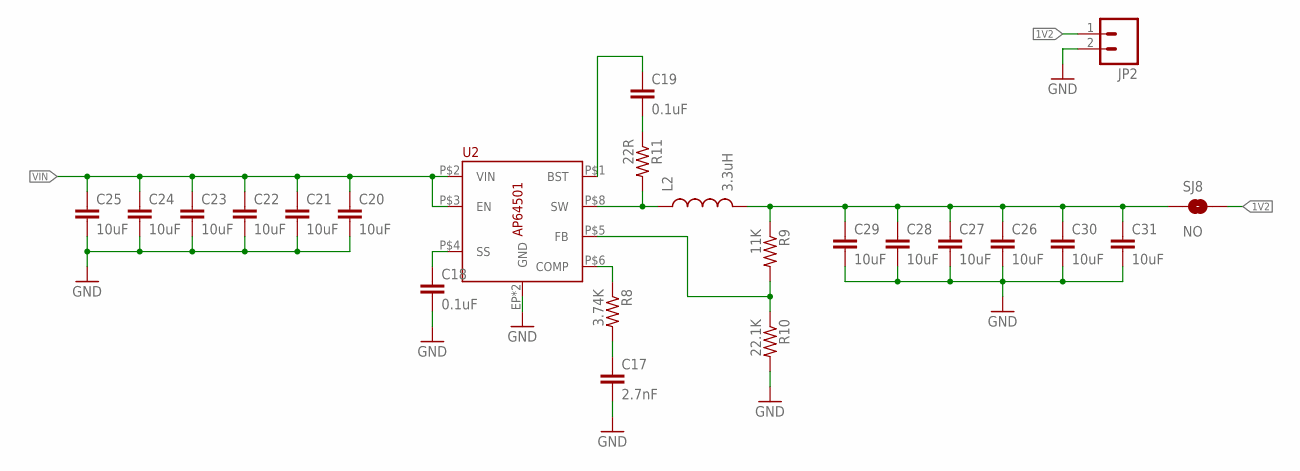
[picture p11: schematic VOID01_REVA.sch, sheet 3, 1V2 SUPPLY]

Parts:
C17: 2.7nF; 0603-CAP
C18, C19: 0.1uF; 0603-CAP
C20, C21, C22, C23, C24, C25, C26, C27, C28, C29, C30, C31: 10uF; 1206
JP2: M02PTH3; 1X02_LONGPADS
L2: 3.3uH; SRN6045TA
R8: 3.74K; 0603-RES
R9: 11K; 0603-RES
R10: 22.1K; 0603-RES
R11: 22R; 0603-RES
SJ8: NO; SJ_2S-NO
U2: AP64501; SO-8EP

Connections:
1V2: JP2.1, SJ8.2; also elsewhere on the board
GND: C17.2, C18.2, C20.2, C21.2, C22.2, C23.2, C24.2, C25.2, C26.2, C27.2, C28.2, C29.2, C30.2, C31.2, JP2.2, R10.2, U2.EP (GND), U2.P$7 (GND); also elsewhere on the board
unnamed: C18.1, U2.P$4 (SS)
unnamed: R8.1, U2.P$6 (COMP)
unnamed: C17.1, R8.2
unnamed: R9.2, R10.1, U2.P$5 (FB)
unnamed: L2.P$1 (1), R11.2, U2.P$8 (SW)
unnamed: C19.2, R11.1
unnamed: C19.1, U2.P$1 (BST)
unnamed: C26.1, C27.1, C28.1, C29.1, C30.1, C31.1, L2.P$2 (2), R9.1, SJ8.1
VIN: C20.1, C21.1, C22.1, C23.1, C24.1, C25.1, U2.P$2 (VIN), U2.P$3 (EN); also elsewhere on the board

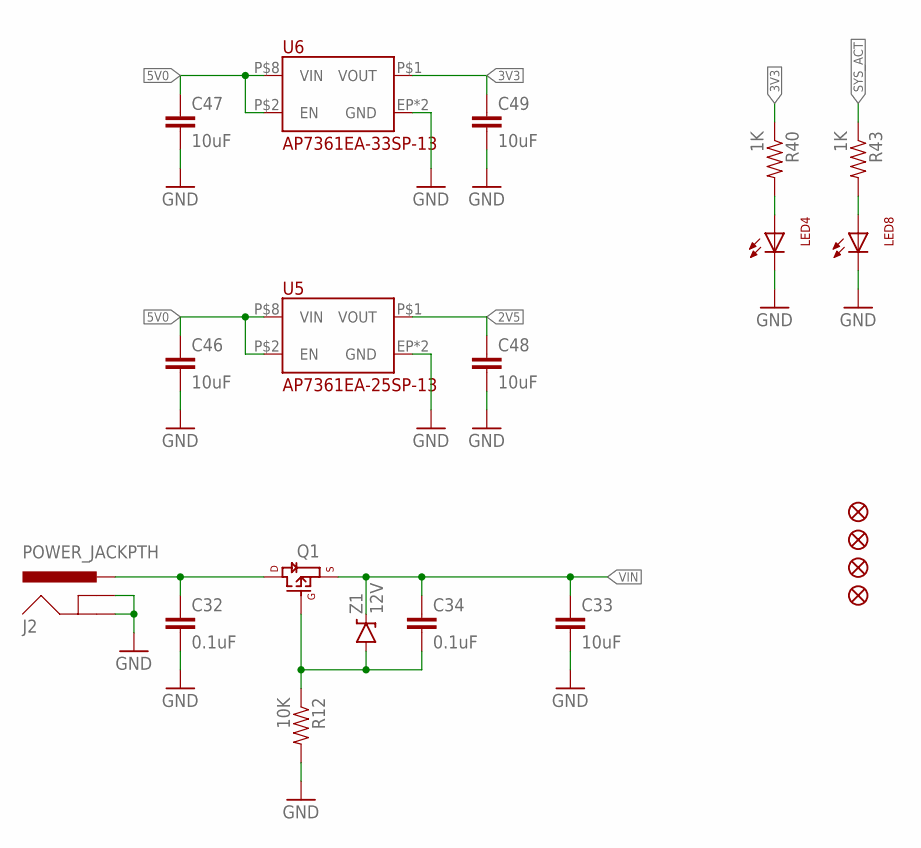
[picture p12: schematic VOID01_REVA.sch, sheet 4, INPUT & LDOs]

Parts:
C32, C34: 0.1uF; 0603-CAP
C33, C46, C47, C48, C49: 10uF; 1206
FID1, FID2, FID3, FID4: FIDUCIAL
J2: POWER_JACKPTH; POWER_JACK_PTH
LED4, LED8: LED; LED_QBL7XX80D-MP4A
Q1: MOSFET_P_CHANNELDMP4015SSS; SO08
R12: 10K; 0603-RES
R40, R43: 1K; 0603-RES
U5: AP7361EA-25SP-13; SO-8EP
U6: AP7361EA-33SP-13; SO-8EP
Z1: 12V; SOT-23

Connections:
2V5: C48.1, U5.P$1 (VOUT); also elsewhere on the board
3V3: C49.1, R40.1, U6.P$1 (VOUT); also elsewhere on the board
5V0: C46.1, C47.1, U5.P$2 (EN), U5.P$8 (VIN), U6.P$2 (EN), U6.P$8 (VIN); also elsewhere on the board
GND: C32.2, C33.2, C46.2, C47.2, C48.2, C49.2, J2.GND, J2.GNDBREAK, LED4.C, LED8.C, R12.2, U5.EP (GND), U5.P$4 (GND), U6.EP (GND), U6.P$4 (GND); also elsewhere on the board
unnamed: C32.1, J2.PWR, Q1.5 (D), Q1.6 (D), Q1.7 (D), Q1.8 (D)
unnamed: C34.2, Q1.4 (G), R12.1, Z1.1 (A)
unnamed: LED8.A, R43.2
unnamed: LED4.A, R40.2
SYS_ACT: R43.1; also elsewhere on the board
VIN: C33.1, C34.1, Q1.1 (S), Q1.2 (S), Q1.3 (S), Z1.3 (C); also elsewhere on the board

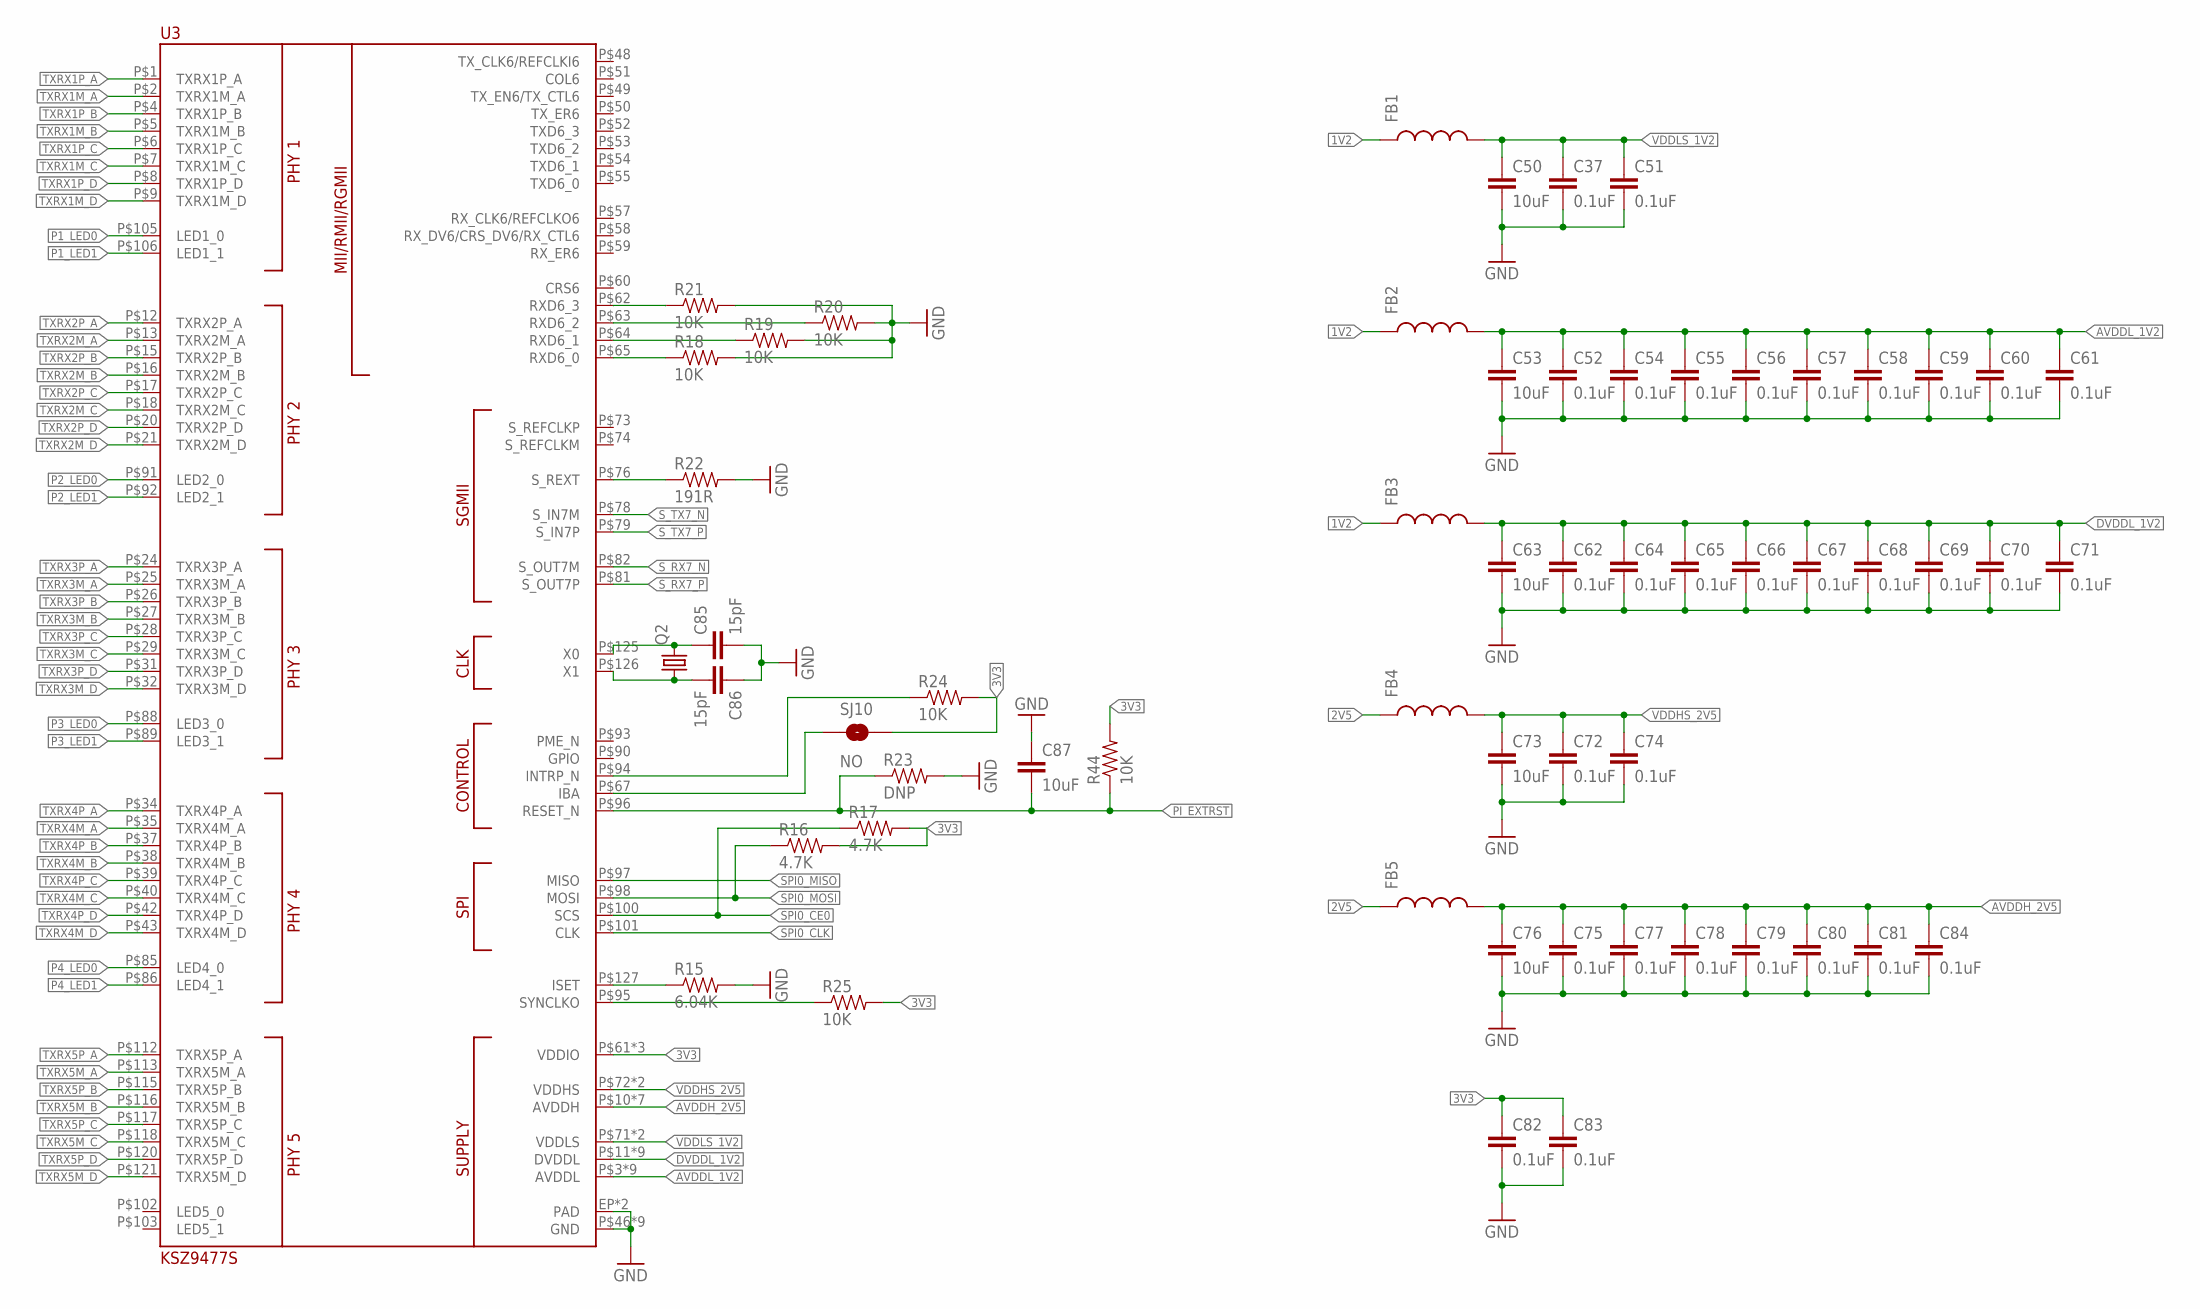
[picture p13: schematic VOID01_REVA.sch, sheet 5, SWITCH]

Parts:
C37, C51, C52, C54, C55, C56, C57, C58, C59, C60, C61, C62, C64, C65, C66, C67, C68, C69, C70, C71, C72, C74, C75, C77, C78, C79, C80, C81, C82, C83, C84: 0.1uF; 0402-CAP
C50, C53, C63, C73, C76, C87: 10uF; 1206
C85, C86: 15pF; 0402-CAP
FB1, FB2, FB3, FB4, FB5: INDUCTOR0805; 0805
Q2: CRYSTAL3.2X2.5; CRYSTAL_3.2X2.5
R15: 6.04K; 0402-RES
R16, R17: 4.7K; 0402-RES
R18, R19, R20, R21, R24, R25, R44: 10K; 0402-RES
R22: 191R; 0402-RES
R23: DNP; 0402-RES
SJ10: NO; SJ_2S-NO
U3: KSZ9477S; TQFP-128-EP

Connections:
1V2: FB1.1, FB2.1, FB3.1; also elsewhere on the board
2V5: FB4.1, FB5.1; also elsewhere on the board
3V3: C82.1, C83.1, R16.2, R17.2, R24.2, R25.2, R44.2, SJ10.2, U3.P$61 (VDDIO), U3.P$68 (VDDIO), U3.P$99 (VDDIO); also elsewhere on the board
AVDDH_2V5: C75.1, C76.1, C77.1, C78.1, C79.1, C80.1, C81.1, C84.1, FB5.2, U3.P$10 (AVDDH), U3.P$22 (AVDDH), U3.P$33 (AVDDH), U3.P$44 (AVDDH), U3.P$111 (AVDDH), U3.P$122 (AVDDH), U3.P$128 (AVDDH)
AVDDL_1V2: C52.1, C53.1, C54.1, C55.1, C56.1, C57.1, C58.1, C59.1, C60.1, C61.1, FB2.2, U3.P$3 (AVDDL), U3.P$14 (AVDDL), U3.P$19 (AVDDL), U3.P$30 (AVDDL), U3.P$36 (AVDDL), U3.P$41 (AVDDL), U3.P$114 (AVDDL), U3.P$119 (AVDDL), U3.P$124 (AVDDL)
DVDDL_1V2: C62.1, C63.1, C64.1, C65.1, C66.1, C67.1, C68.1, C69.1, C70.1, C71.1, FB3.2, U3.P$11 (DVDDL), U3.P$23 (DVDDL), U3.P$45 (DVDDL), U3.P$56 (DVDDL), U3.P$66 (DVDDL), U3.P$70 (DVDDL), U3.P$87 (DVDDL), U3.P$104 (DVDDL), U3.P$110 (DVDDL)
GND: C37.2, C50.2, C51.2, C52.2, C53.2, C54.2, C55.2, C56.2, C57.2, C58.2, C59.2, C60.2, C61.2, C62.2, C63.2, C64.2, C65.2, C66.2, C67.2, C68.2, C69.2, C70.2, C71.2, C72.2, C73.2, C74.2, C75.2, C76.2, C77.2, C78.2, C79.2, C80.2, C81.2, C82.2, C83.2, C84.2, C85.2, C86.1, C87.1, R15.2, R18.2, R19.2, R20.2, R21.2, R22.2, R23.2, U3.EP (PAD), U3.EP1 (PAD), U3.P$46 (GND), U3.P$47 (GND), U3.P$69 (GND), U3.P$75 (GND), U3.P$77 (GND), U3.P$80 (GND), U3.P$107 (GND), U3.P$109 (GND), U3.P$123 (GND); also elsewhere on the board
unnamed: R15.1, U3.P$127 (ISET)
unnamed: R21.1, U3.P$62 (RXD6_3)
unnamed: R20.1, U3.P$63 (RXD6_2)
unnamed: R19.1, U3.P$64 (RXD6_1)
unnamed: R18.1, U3.P$65 (RXD6_0)
unnamed: R22.1, U3.P$76 (S_REXT)
unnamed: R25.1, U3.P$95 (SYNCLKO)
unnamed: R24.1, U3.P$94 (INTRP_N)
unnamed: SJ10.1, U3.P$67 (IBA)
unnamed: C86.2, Q2.P$1 (1), U3.P$126 (X1)
unnamed: C85.1, Q2.P$3 (2), U3.P$125 (X0)
P1_LED0: U3.P$105 (LED1_0); also elsewhere on the board
P1_LED1: U3.P$106 (LED1_1); also elsewhere on the board
P2_LED0: U3.P$91 (LED2_0); also elsewhere on the board
P2_LED1: U3.P$92 (LED2_1); also elsewhere on the board
P3_LED0: U3.P$88 (LED3_0); also elsewhere on the board
P3_LED1: U3.P$89 (LED3_1); also elsewhere on the board
P4_LED0: U3.P$85 (LED4_0); also elsewhere on the board
P4_LED1: U3.P$86 (LED4_1); also elsewhere on the board
PI_EXTRST: C87.2, R23.1, R44.1, U3.P$96 (RESET_N); also elsewhere on the board
SPI0_CE0: R17.1, U3.P$100 (SCS); also elsewhere on the board
SPI0_CLK: U3.P$101 (CLK); also elsewhere on the board
SPI0_MISO: U3.P$97 (MISO); also elsewhere on the board
SPI0_MOSI: R16.1, U3.P$98 (MOSI); also elsewhere on the board
S_RX7_N: U3.P$82 (S_OUT7M); also elsewhere on the board
S_RX7_P: U3.P$81 (S_OUT7P); also elsewhere on the board
S_TX7_N: U3.P$78 (S_IN7M); also elsewhere on the board
S_TX7_P: U3.P$79 (S_IN7P); also elsewhere on the board
TXRX1M_A: U3.P$2 (TXRX1M_A); also elsewhere on the board
TXRX1M_B: U3.P$5 (TXRX1M_B); also elsewhere on the board
TXRX1M_C: U3.P$7 (TXRX1M_C); also elsewhere on the board
TXRX1M_D: U3.P$9 (TXRX1M_D); also elsewhere on the board
TXRX1P_A: U3.P$1 (TXRX1P_A); also elsewhere on the board
TXRX1P_B: U3.P$4 (TXRX1P_B); also elsewhere on the board
TXRX1P_C: U3.P$6 (TXRX1P_C); also elsewhere on the board
TXRX1P_D: U3.P$8 (TXRX1P_D); also elsewhere on the board
TXRX2M_A: U3.P$13 (TXRX2M_A); also elsewhere on the board
TXRX2M_B: U3.P$16 (TXRX2M_B); also elsewhere on the board
TXRX2M_C: U3.P$18 (TXRX2M_C); also elsewhere on the board
TXRX2M_D: U3.P$21 (TXRX2M_D); also elsewhere on the board
TXRX2P_A: U3.P$12 (TXRX2P_A); also elsewhere on the board
TXRX2P_B: U3.P$15 (TXRX2P_B); also elsewhere on the board
TXRX2P_C: U3.P$17 (TXRX2P_C); also elsewhere on the board
TXRX2P_D: U3.P$20 (TXRX2P_D); also elsewhere on the board
TXRX3M_A: U3.P$25 (TXRX3M_A); also elsewhere on the board
TXRX3M_B: U3.P$27 (TXRX3M_B); also elsewhere on the board
TXRX3M_C: U3.P$29 (TXRX3M_C); also elsewhere on the board
TXRX3M_D: U3.P$32 (TXRX3M_D); also elsewhere on the board
TXRX3P_A: U3.P$24 (TXRX3P_A); also elsewhere on the board
TXRX3P_B: U3.P$26 (TXRX3P_B); also elsewhere on the board
TXRX3P_C: U3.P$28 (TXRX3P_C); also elsewhere on the board
TXRX3P_D: U3.P$31 (TXRX3P_D); also elsewhere on the board
TXRX4M_A: U3.P$35 (TXRX4M_A); also elsewhere on the board
TXRX4M_B: U3.P$38 (TXRX4M_B); also elsewhere on the board
TXRX4M_C: U3.P$40 (TXRX4M_C); also elsewhere on the board
TXRX4M_D: U3.P$43 (TXRX4M_D); also elsewhere on the board
TXRX4P_A: U3.P$34 (TXRX4P_A); also elsewhere on the board
TXRX4P_B: U3.P$37 (TXRX4P_B); also elsewhere on the board
TXRX4P_C: U3.P$39 (TXRX4P_C); also elsewhere on the board
TXRX4P_D: U3.P$42 (TXRX4P_D); also elsewhere on the board
TXRX5M_A: U3.P$113 (TXRX5M_A); also elsewhere on the board
TXRX5M_B: U3.P$116 (TXRX5M_B); also elsewhere on the board
TXRX5M_C: U3.P$118 (TXRX5M_C); also elsewhere on the board
TXRX5M_D: U3.P$121 (TXRX5M_D); also elsewhere on the board
TXRX5P_A: U3.P$112 (TXRX5P_A); also elsewhere on the board
TXRX5P_B: U3.P$115 (TXRX5P_B); also elsewhere on the board
TXRX5P_C: U3.P$117 (TXRX5P_C); also elsewhere on the board
TXRX5P_D: U3.P$120 (TXRX5P_D); also elsewhere on the board
VDDHS_2V5: C72.1, C73.1, C74.1, FB4.2, U3.P$72 (VDDHS), U3.P$83 (VDDHS)
VDDLS_1V2: C37.1, C50.1, C51.1, FB1.2, U3.P$71 (VDDLS), U3.P$84 (VDDLS)

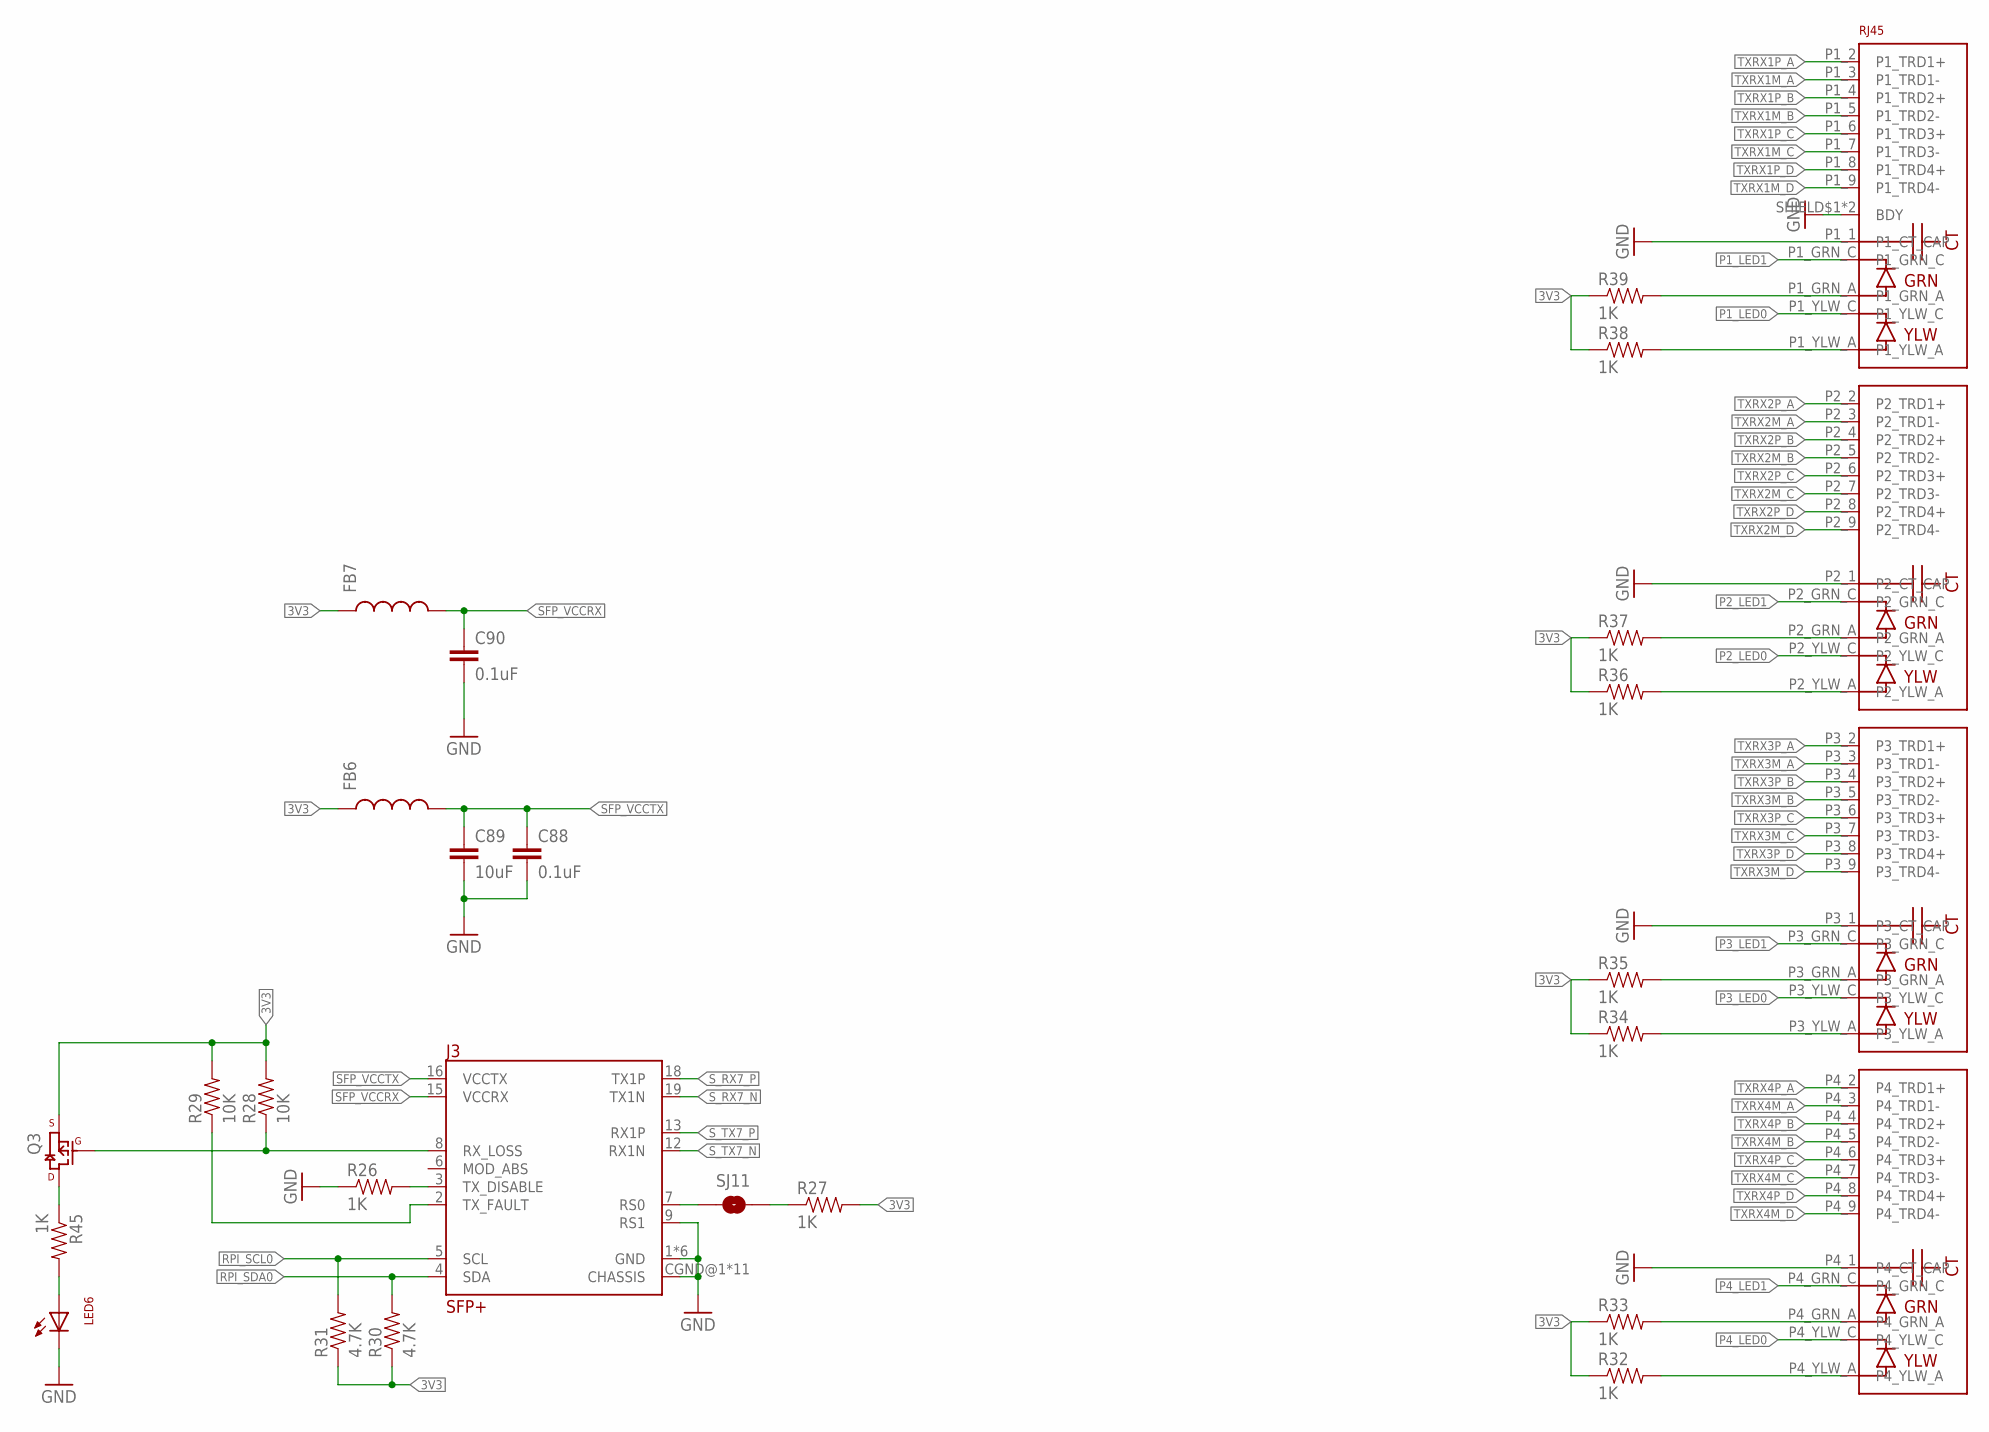
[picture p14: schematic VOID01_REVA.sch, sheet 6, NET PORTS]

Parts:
C88, C90: 0.1uF; 0402-CAP
C89: 10uF; 1206
FB6, FB7: INDUCTOR0805; 0805
J3: SFP; SFP_SOCKET_CAGE
J4: JXD0-4015NL
LED6: LED; LED_QBL7XX80D-MP4A
Q3: MOSFET_P_CHANNELAO3423; SOT-23
R26, R27: 1K; 0402-RES
R28: 10K; 0603-RES
R29: 10K; 0402-RES
R30, R31: 4.7K; 0402-RES
R32, R33, R34, R35, R36, R37, R38, R39, R45: 1K; 0603-RES
SJ11: SOLDERJUMPERNO; SJ_2S-NO

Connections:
3V3: FB6.1, FB7.1, Q3.2 (S), R27.2, R28.2, R29.2, R30.1, R31.1, R32.1, R33.1, R34.1, R35.1, R36.1, R37.1, R38.1, R39.1; also elsewhere on the board
GND: C88.2, C89.2, C90.2, J3.1 (GND), J3.9 (RS1), J3.10 (GND), J3.11 (GND), J3.14 (GND), J3.17 (GND), J3.20 (GND), J3.CGND@1 (CHASSIS), J3.CGND@6 (CHASSIS), J3.CGND@9 (CHASSIS), J3.CGND@11 (CHASSIS), J3.CGND@12 (CHASSIS), J3.CGND@13 (CHASSIS), J3.CGND@14 (CHASSIS), J3.CGND@15 (CHASSIS), J3.CGND@16 (CHASSIS), J3.CGND@19 (CHASSIS), J3.CGND@20 (CHASSIS), J4.P1_1 (P1_CT_CAP), J4.P2_1 (P2_CT_CAP), J4.P3_1 (P3_CT_CAP), J4.P4_1 (P4_CT_CAP), J4.SHIELD$1 (BDY), J4.SHIELD$5 (BDY), LED6.C, R26.1; also elsewhere on the board
unnamed: J4.P4_YLW_A, R32.2
unnamed: J4.P4_GRN_A, R33.2
unnamed: J4.P3_GRN_A, R35.2
unnamed: J4.P3_YLW_A, R34.2
unnamed: J4.P2_GRN_A, R37.2
unnamed: J4.P2_YLW_A, R36.2
unnamed: J4.P1_GRN_A, R39.2
unnamed: J4.P1_YLW_A, R38.2
unnamed: J3.3 (TX_DISABLE), R26.2
unnamed: J3.7 (RS0), SJ11.1
unnamed: R27.1, SJ11.2
unnamed: J3.8 (RX_LOSS), Q3.1 (G), R28.1
unnamed: J3.2 (TX_FAULT), R29.1
unnamed: LED6.A, R45.2
unnamed: Q3.3 (D), R45.1
P1_LED0: J4.P1_YLW_C; also elsewhere on the board
P1_LED1: J4.P1_GRN_C; also elsewhere on the board
P2_LED0: J4.P2_YLW_C; also elsewhere on the board
P2_LED1: J4.P2_GRN_C; also elsewhere on the board
P3_LED0: J4.P3_YLW_C; also elsewhere on the board
P3_LED1: J4.P3_GRN_C; also elsewhere on the board
P4_LED0: J4.P4_YLW_C; also elsewhere on the board
P4_LED1: J4.P4_GRN_C; also elsewhere on the board
RPI_SCL0: J3.5 (SCL), R31.2; also elsewhere on the board
RPI_SDA0: J3.4 (SDA), R30.2; also elsewhere on the board
SFP_VCCRX: C90.1, FB7.2, J3.15 (VCCRX)
SFP_VCCTX: C88.1, C89.1, FB6.2, J3.16 (VCCTX)
S_RX7_N: J3.19 (TX1N); also elsewhere on the board
S_RX7_P: J3.18 (TX1P); also elsewhere on the board
S_TX7_N: J3.12 (RX1N); also elsewhere on the board
S_TX7_P: J3.13 (RX1P); also elsewhere on the board
TXRX1M_A: J4.P1_3 (P1_TRD1-); also elsewhere on the board
TXRX1M_B: J4.P1_5 (P1_TRD2-); also elsewhere on the board
TXRX1M_C: J4.P1_7 (P1_TRD3-); also elsewhere on the board
TXRX1M_D: J4.P1_9 (P1_TRD4-); also elsewhere on the board
TXRX1P_A: J4.P1_2 (P1_TRD1+); also elsewhere on the board
TXRX1P_B: J4.P1_4 (P1_TRD2+); also elsewhere on the board
TXRX1P_C: J4.P1_6 (P1_TRD3+); also elsewhere on the board
TXRX1P_D: J4.P1_8 (P1_TRD4+); also elsewhere on the board
TXRX2M_A: J4.P2_3 (P2_TRD1-); also elsewhere on the board
TXRX2M_B: J4.P2_5 (P2_TRD2-); also elsewhere on the board
TXRX2M_C: J4.P2_7 (P2_TRD3-); also elsewhere on the board
TXRX2M_D: J4.P2_9 (P2_TRD4-); also elsewhere on the board
TXRX2P_A: J4.P2_2 (P2_TRD1+); also elsewhere on the board
TXRX2P_B: J4.P2_4 (P2_TRD2+); also elsewhere on the board
TXRX2P_C: J4.P2_6 (P2_TRD3+); also elsewhere on the board
TXRX2P_D: J4.P2_8 (P2_TRD4+); also elsewhere on the board
TXRX3M_A: J4.P3_3 (P3_TRD1-); also elsewhere on the board
TXRX3M_B: J4.P3_5 (P3_TRD2-); also elsewhere on the board
TXRX3M_C: J4.P3_7 (P3_TRD3-); also elsewhere on the board
TXRX3M_D: J4.P3_9 (P3_TRD4-); also elsewhere on the board
TXRX3P_A: J4.P3_2 (P3_TRD1+); also elsewhere on the board
TXRX3P_B: J4.P3_4 (P3_TRD2+); also elsewhere on the board
TXRX3P_C: J4.P3_6 (P3_TRD3+); also elsewhere on the board
TXRX3P_D: J4.P3_8 (P3_TRD4+); also elsewhere on the board
TXRX4M_A: J4.P4_3 (P4_TRD1-); also elsewhere on the board
TXRX4M_B: J4.P4_5 (P4_TRD2-); also elsewhere on the board
TXRX4M_C: J4.P4_7 (P4_TRD3-); also elsewhere on the board
TXRX4M_D: J4.P4_9 (P4_TRD4-); also elsewhere on the board
TXRX4P_A: J4.P4_2 (P4_TRD1+); also elsewhere on the board
TXRX4P_B: J4.P4_4 (P4_TRD2+); also elsewhere on the board
TXRX4P_C: J4.P4_6 (P4_TRD3+); also elsewhere on the board
TXRX4P_D: J4.P4_8 (P4_TRD4+); also elsewhere on the board

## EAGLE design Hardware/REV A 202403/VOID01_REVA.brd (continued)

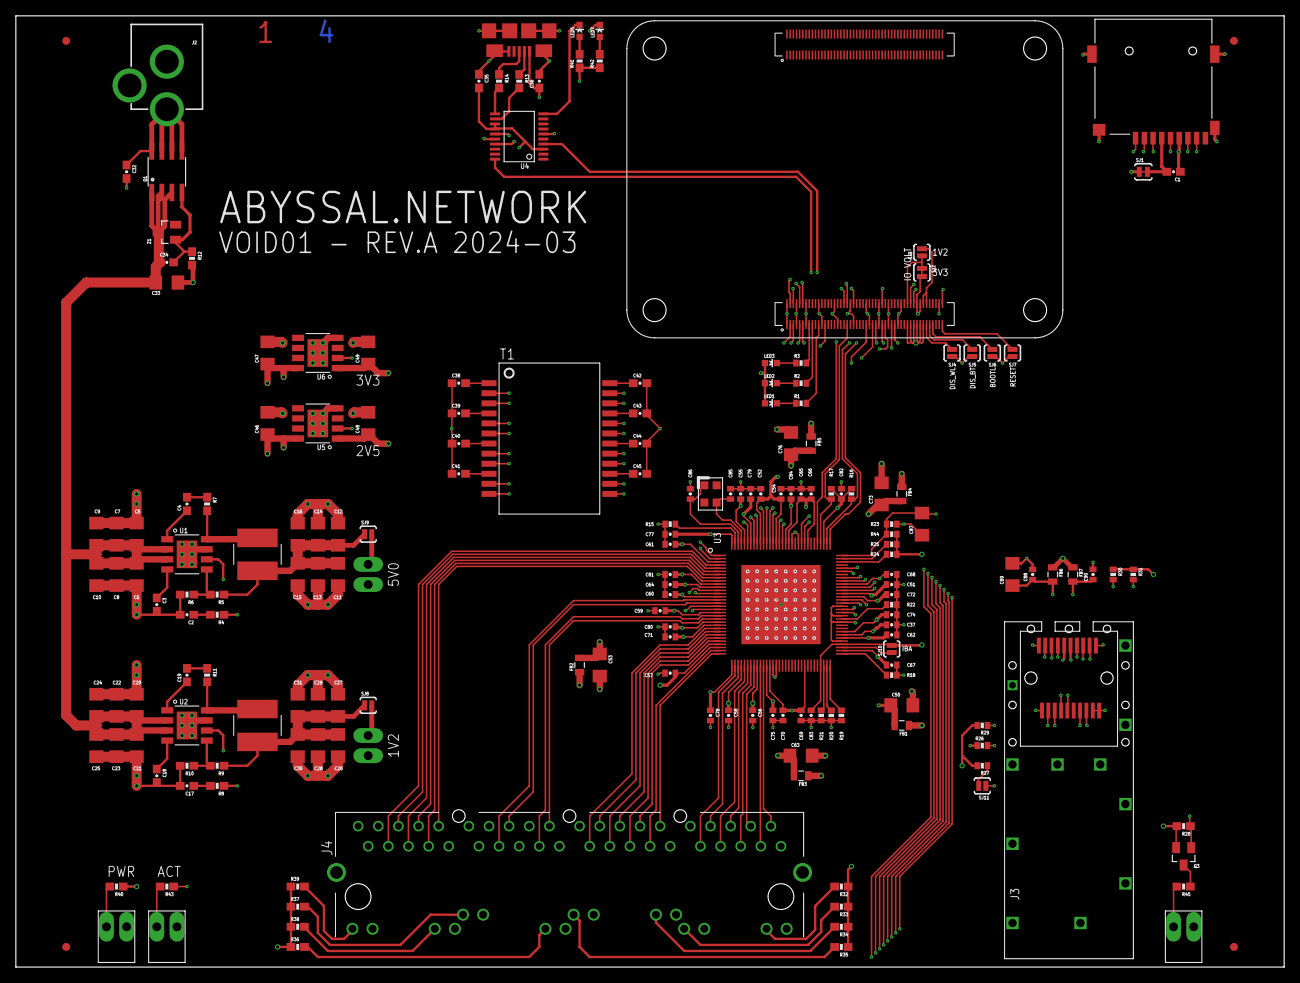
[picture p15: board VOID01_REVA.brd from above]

Board: 4 copper layers, 160.0 x 120.0 mm, 186 parts (0 on the bottom side), 167 nets.

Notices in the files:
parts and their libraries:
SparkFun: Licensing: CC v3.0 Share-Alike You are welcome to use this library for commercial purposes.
